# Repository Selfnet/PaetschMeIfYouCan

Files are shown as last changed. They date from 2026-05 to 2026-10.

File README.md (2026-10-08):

# P-tschMeIfYouCan
Ein Geschicklichkeitsspiel mit Spaß am Gerät

## Important: Name Entry Keyboard Behavior

This is a required interaction contract. Preserve it when changing the dashboard:

- **Enter in the first displayed input:** move to the second input if its name is empty or whitespace-only; otherwise submit both names and proceed to the leaderboard.
- **Enter in the second displayed input:** submit both names and proceed to the leaderboard, even when either name is blank. Empty or whitespace-only names skip that player's leaderboard entry.
- **Tab / Shift+Tab:** cycle between the name inputs, including wrapping; never submit names or advance to the leaderboard, even when both names are filled.

The inputs are displayed in result order (winner first), not fixed player-number order. These rules apply regardless of which player wins or whether the race is tied. Automatic name-entry timeout is separate from keyboard submission.

[Keyboard regression tests](Test_Server/tests/test_name_entry_keyboard.py) execute the dashboard's actual JavaScript handler. Run them when changing name entry or keyboard handling; they do not test live serial hardware.

## Leaderboard Policy

Each leaderboard shows one row per case-insensitive name, separately for each game mode and slot. Ranks compare each player's **best time**; equal times share a rank. The name uses the latest spelling, and **Set at** is the best attempt's timestamp (the latest matching attempt for equal best times). The **Attempts** column counts all saved scores for that name in the same mode and slot, including historical scores. Blank names are still skipped, and retrying a score save does not add an attempt.

After a race, that player's row is highlighted even when the new time is worse. A worse time appears as **This race** beneath the best time without changing the rank. A first score or strictly improved best earns a **NEW PB!** badge; matching an existing best does not. Idle browsing does not show current-race details or badges.

All attempt history remains in SQLite; grouping does not delete or rewrite scores and requires no database migration. A paginated browse freezes the best times, latest attempts, and counts at its opening snapshot. [Leaderboard regression tests](Test_Server/tests/test_leaderboard.py) cover case-insensitive grouping, best-time ranking, attempt counts, and snapshot pagination; [transport tests](Test_Server/tests/test_app.py) cover current-race highlighting and personal-best detection. Neither covers physical hardware or browser layout.

## Leaderboard Slots

Use **1-9**, including the numeric keypad, or the slot selector to choose a leaderboard while the game is ready. The shortcut also works while browsing the idle leaderboard, which refreshes to the selected slot. Slot switching is disabled during a race, name entry, post-race results, and the mode dialog. Digits typed into name inputs remain part of the name.

Each slot has independent scores and ranks for every game mode. Slot 1 retains all existing scores; slots 2-9 start empty. Switching never deletes scores. The selected slot is saved in SQLite and restored after backend or machine restarts, independently of browser storage. The slot is captured when a race starts, so delayed score writes cannot move a race into another slot.

The database remains at `LEADERBOARD_DB` or `~/.local/share/patchmeifyoucan/leaderboard.sqlite3`. Migration adds the slot column and a singleton selection setting without changing historical score IDs, timestamps, or mode IDs. Back up the database before deploying this migration. Source-only rollback to pre-slot code is unsafe: that code would combine all slots' scores. A database rollback also discards any scores recorded since its backup.

[Slot persistence and transport tests](Test_Server/tests/test_leaderboard_slots.py) cover migration, isolation, restart restoration, failed settings writes, race identity, and stale page rejection; they do not exercise physical hardware. [Slot keyboard tests](Test_Server/tests/test_leaderboard_slot_keyboard.py) execute the actual dashboard shortcut and selection helpers, including modifier, focus, and phase guards; they do not replace browser layout checks.

## Development

[Adding gamemodes](docs/gamemode-authoring.md) explains the board/session contract, registry, validation, and scoring identities. Start there when adding a mode; firmware protocols and deployment are outside its scope.

Run `uv run pytest -q` from `Test_Server/`. Node.js must be on `PATH` for the name-entry keyboard tests, which execute the dashboard's JavaScript handler.

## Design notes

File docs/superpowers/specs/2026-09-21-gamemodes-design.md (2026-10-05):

# Gamemodes Design

## Status and Goal

Historical design, implemented and deployed on `feat/gamemodes` through `194a6cb`. [The README](../../../README.md) documents the current name-entry keyboard contract and test prerequisites; this document records the original design, not current deployment instructions.

The gameplay and interaction decisions below reflect the conversation. Technical defaults introduced while writing this spec include 50-row pages, snapshot pagination, tick precision, and the detailed focus and error contracts. These are proposed implementation choices for review, not separately approved product requirements.

Introduce extensible, stateful gamemodes without changing the familiar switch overview and race flow. Ship Full Field, Half Field, and Quarter Field first. Keep mode logic independent of Flask, the browser, serial transport, and persistence so contributors can add modes without changing those integrations.

Work happens on `feat/gamemodes` in the canonical checkout's `.worktrees/gamemodes/` directory. Deployment is not part of this work.

## Existing Context

- `Test_Server/app.py` currently owns cached board feedback, expected cable identities, serial parsing, and application wiring. Serial readings become open/wrong/correct states before reaching the race.
- `Test_Server/race.py` owns the locked race lifecycle and hardcodes completion as all 48 ports being correct.
- `Test_Server/templates/index.html` renders each board as two rows of 24 ports. Port indices alternate top/bottom: column `i // 2`, row `i % 2`.
- `Test_Server/leaderboard.py` stores mode-independent scores and queries the top 10.
- `Test_Firmware/src/main.cpp` reads port identities and drives yellow/green LEDs locally. It does not receive host LED commands.

Related designs:

- [Post-race results](2026-08-28-post-race-leaderboard-design.md): background for race timing, result entry, persistence, and failure handling. This spec replaces its all-48 completion rule, top-10 restriction, and fixed leaderboard deadline; it is not an authoritative description of later name-entry changes.
- [Idle leaderboard](2026-08-30-idle-leaderboard-design.md): background for local browsing, dismissal, timestamps, and stale-response protection. This spec replaces its top-10 restriction and adds scrolling and navigation-driven inactivity handling; it does not redesign race controls.

Preserve current working behavior outside the changes explicitly described here, including simultaneous name-entry support, ties, per-player diagnostic stops, and result timing.

## Scope

Included:

- Board observations separated from mode-specific interpretation.
- Stateful, independently testable per-player mode sessions.
- Three built-in field modes and a documented authoring interface.
- A hidden keyboard-accessible main-screen mode selector.
- Generic mode objective, progress, stage, and port presentation.
- A hardware-independent boundary for future LED output.
- Per-mode leaderboards, existing-score migration, all-score browsing, and inactivity handling.

Excluded:

- Firmware modifications, a serial LED protocol, or sending LED commands.
- Plugin discovery, uploaded code, hot reloading, or a custom-mode editor.
- Additional shipped gameplay beyond the three field modes.
- Empty-board enforcement, anti-cheat measures, or fresh-insertion requirements for field modes.
- Leaderboard deletion or administration, durable recovery of unfinished races, and deployment.

## Built-in Rules

Each player has a separate 48-port board, arranged as two rows of 24 columns. Both players use the same selected mode.

| Mode ID | Label | Required region | Required ports |
| --- | --- | --- | --- |
| `full-field` | Full Field | All 24 columns | 48, indices 0-47 |
| `half-field` | Half Field | Leftmost 12 columns | 24, indices 0-23 |
| `quarter-field` | Quarter Field | Leftmost six columns | 12, indices 0-11 |

Half and Quarter Field are single-region objectives, not left-to-right sequences. Quarter Field therefore requires six top and six bottom ports. Ports outside the region are ignored, regardless of whether they are open, correct, or incorrectly patched.

All three modes reuse one implementation parameterized by required ports. In normal verification mode, each required port must contain its expected cable identity. Preserve the existing verification-bypass diagnostic behavior: occupied required ports count when verification is disabled. Verification is explicit evaluation context, not inferred from rendered feedback.

There is no unplugging prerequisite. Pre-patched ports count. At race start, evaluate the latest valid observation at elapsed time zero; an already-complete board may finish immediately. If no valid reading has arrived, the board is unknown and cannot complete until a valid observation is received. Do not add anti-cheat logic.

## Architecture

### GameBoard

One `GameBoard` per player owns the latest validated raw port identities and whether any valid observation has arrived. It exposes immutable observation snapshots and the fixed physical layout, including expected identities and coordinate/index helpers.

Keep raw identities available to custom modes rather than reducing all input to open/wrong/correct. Board updates must contain exactly 48 integer byte values; reject booleans, out-of-range values, malformed text, and partial frames. A rejected update leaves the previous observation intact and is not delivered to a session.

The serial adapter remains responsible for decoding and reversing wire order into the canonical port order. That reversal happens once. Modes do not know serial devices, wire ordering, or LED shift-register mappings.

### GameMode and ModeSession

A mode definition provides a stable ID, label, description, and a factory for fresh sessions. Use an explicit in-process registry with unique IDs; no dynamic plugin loading. Invalid definitions fail startup clearly rather than silently replacing another mode.

Each player receives a separate session at race start. A session owns its private gameplay state and supports:

- Initialization against the current observation and evaluation context at elapsed time zero.
- Observation updates with an immutable board snapshot and monotonic elapsed time.
- Periodic ticks with the latest observation and elapsed time, allowing timed stages to progress without new serial input.
- An immutable presentation snapshot after evaluation.

Reset or abandonment discards sessions. Sessions must not retain state across races or share mutable gameplay state between players. They have no Flask, Socket.IO, database, serial, or wall-clock dependencies and must not block on I/O.

The session snapshot contains:

- Short objective text and an optional stage label.
- Progress as a non-negative current value and positive total, with a short unit label; omit progress for objectives without a meaningful counter.
- Per-port target membership and semantic feedback: open, wrong, correct, or unknown. Inactive appearance is derived from target membership, not a substitute for the observation.
- A completion flag.
- Optional desired per-port LED states, described below.

Field modes report correct required ports out of required ports, for example `8 / 12 correct`. Stateful modes can change targets, instructions, and stages through the same contract. The browser contains no mode-ID-specific gameplay branches.

A pure ready-state preview supplies targets and presentation from current observations without advancing a race session. This preserves live board feedback before a race while ensuring race start always creates fresh gameplay state.

### Race Controller and Runtime

The race controller owns selection, race lifecycle, per-player session ownership, timing, result ordering, name entry, and deadlines. The selected mode is fixed for the entire race and its results. The runtime handles transport, persistence, and broadcasting.

Serialize selection, start, reset, observation delivery, tick evaluation, and completion under the authoritative controller lock. Capture one monotonic timestamp per transition so both start evaluations use the same origin. Never run persistence, serial I/O, or socket emission while holding that lock; publish immutable snapshots and transition results afterward.

Publish each validated board observation and deliver it to the current session in the same locked transition. Start reads both current boards, creates both sessions, and evaluates both at the shared start timestamp in one locked transition. Serial decoding can happen outside the lock, but cached snapshots must not be captured there and subsequently delivered to a replacement session. Lock acquisition determines whether an observation precedes or follows start/reset.

First completion remains latched. Later observations, ticks, or unplugging cannot change the recorded finish time. Preserve millisecond floor timing and existing manual-stop behavior. Ordinary mode progression must be broadcast even when race phase and completion status do not change.

An individual diagnostic stop freezes that player's displayed clock, but while the shared phase remains racing the unfinished session continues receiving observations and ticks using elapsed time from the original race start. A later completion replaces the manual stop with its actual completion timestamp. Global stop, or stopping both players, ends evaluation for all sessions; physical observations may still update. Reset discards those sessions. Completed sessions no longer advance.

Out-of-lock operations carry immutable origin tokens. Score persistence carries the completed race ID and mode ID; page reads carry the browsing request ID, mode ID, snapshot boundary, and race ID for post-race views. Apply resulting controller updates only if the expected race, mode, and phase still match. A late write may finish saving already-confirmed submissions, but cannot modify a replacement race or revive an expired view. Browser responses are likewise checked against the active browsing token. Persistence and page responses never refresh inactivity deadlines.

Use the existing periodic background mechanism for ticks; this version promises no sub-second scheduling for time-driven modes. Pass actual elapsed monotonic time, not a count of ticks. Serial-driven completion retains its arrival-time resolution.

## Lifecycle and Errors

- Server startup selects Full Field.
- Selection is accepted only in `ready`, with a known registered mode ID. Both players change together.
- Selection survives explicit resets, leaderboard dismissal, and automatic return to ready. It does not persist across server restarts.
- Start creates new independent sessions and evaluates current valid observations immediately.
- Reset discards mode progress but retains physical observations and selected mode.
- A reconnect receives mode metadata, phase, objective, progress, port feedback, and current race identity without reconstructing gameplay in JavaScript.
- Invalid hardware input is rejected before mode evaluation.
- A session exception or invalid output stops the race with a visible, recoverable error, logs diagnostic details, and creates no leaderboard submissions. Reset returns to ready. A failing ready preview shows an error and prevents starting that mode, while still allowing another mode to be selected.

## Main-Screen UI

### Mode Selector

The switch overview remains the default. The mode selector is hidden initially and can be opened only while ready. Display a compact current-mode label, such as `Quarter Field · 12 ports`, and a subtle `M: mode` hint while ready. Other modes can omit the port count if inappropriate.

- `M` opens the selector; `M` again cancels it.
- Arrow keys move between options in registry order without wrapping at the ends.
- Tab and Shift+Tab move focus through selectable options and the close control in normal DOM order.
- Enter or clicking an option confirms it, updates the shared selected mode, and closes the selector.
- Escape cancels without changing the selection.
- Space does not start a race while the selector is open.
- Opening focuses the selected mode. Closing restores focus to the overview's mode control.

Each option shows its label and short description. Browsing focus does not change the shared selection or preview; only confirmation does. The selector's visibility and focus are browser-local. Accepted selection is broadcast to every browser. An authoritative phase change closes any open selector. Stale selection requests after a race starts are rejected.

Use a labeled modal dialog with ordinary option buttons and a close button. Background controls are inert while it is open. Tab/Shift+Tab visits every option and the close button, wrapping at the dialog boundary; arrows move only among mode options. If another browser changes the mode, update the selected marker without moving the local browsing focus. Enter confirms the locally focused option. On an external phase change, move focus to an appropriate element of the new view rather than a now-hidden mode control.

Mode shortcuts never intercept text entry; `M` remains a normal character in a name field. The selector and local leaderboard cannot be open simultaneously; their shortcuts do not open one behind the other.

### Board Presentation

Keep all 48 physical positions visible in the existing two-row arrangement. Required ports retain clear open/wrong/correct feedback. Unused ports are dimmed with readable numbers, and their state does not affect objective progress.

Show a concise objective and progress for each player, plus a stage label when present. Independent player sessions may show different stages and targets. Preserve timers and existing result/name-entry screens. Mode identity remains visible on results and leaderboards so the meaning of a time is clear.

Unknown observations are not presented as verified empty ports. Accessibility labels identify port number, whether it is required, and its feedback. Focus must remain visibly distinct from completion highlighting.

## Future LED Boundary

Sessions may describe optional LED intent as a complete 48-port frame of yellow/green boolean states. Absence means the mode supplies no host LED intent; it is distinct from an explicitly all-off frame. Frames describe desired state, not commands or electrical indices.

LED intent is separate from browser feedback because their capabilities differ. A future hardware adapter can map canonical port indices to firmware commands and handle capability negotiation, writes, and reconnects without changing game rules.

This version validates and tests the output contract but does not send it. Existing firmware behavior remains unchanged. It does not introduce blinking, brightness, animations, transport retries, or a new wire protocol.

## Per-Mode Leaderboards

### Persistence and Ranking

Store a stable mode ID with each score, propagated from the completed race through score submission. Never infer score mode from the current selection at insertion time.

Migrate all existing rows to `full-field`, preserving IDs, names, times, timestamps, and race/player uniqueness. Migration must be transactional and safe on repeated initialization. Add an index supporting per-mode score ordering.

Rank only within the selected mode. Preserve competition ranking for equal millisecond durations and deterministic ordering by duration, creation time, then database ID. Mode IDs are durable scoring identities: incompatible rule changes should receive a new ID rather than silently sharing old rankings.

The post-race leaderboard uses the completed race's mode. The local leaderboard uses the current selected mode. Keep rank, name, time, and locally formatted creation timestamp columns, and current-race highlighting wherever those rows occur.

### All-Score Browsing

Expose every score for the mode, not just the top 10. Fetch bounded pages on demand, initially 50 rows per page. A browsing snapshot captures the maximum included row ID on opening, and every page filters to that boundary. New inserts become visible when reopening, preventing duplicates or skipped rows as new scores arrive during browsing. Ranking is computed across the entire mode snapshot before pagination, not separately per page.

Use boundary `0` for an empty snapshot. Every page applies both the mode filter and `id <= boundary`, even for an empty snapshot. Page position is a validated non-negative offset into that snapshot's deterministic ordering. Deletion and editing of scores are outside this feature, so inserts alone cannot shift offsets within the boundary.

Requests and targeted responses identify the mode, browsing request, snapshot boundary, and page position. Validate bounds server-side and keep the page size capped. Each browser tracks its own rows, focus, and scroll position. Ignore responses belonging to a closed view, previous mode, old race, or replaced browsing request.

Do not put the growing row collection in periodic shared `game_state` broadcasts. Shared state supplies race identity, mode, timeout, and persistence status; targeted page responses supply rows. Periodic countdown updates must not recreate the table or reset browsing position.

If the selected mode changes in another browser, close the local leaderboard so it cannot continue displaying an incorrectly labeled mode. An active race transition also closes the local view, as today.

### Keyboard and Scrolling

Use a bounded scroll area inside the leaderboard view rather than scrolling the entire kiosk page. Open at the highest-ranked scores and retain heading focus on entry.

- Up/Down moves through score rows and scrolls the focused row into view. From the heading, Down enters the first row.
- Tab/Shift+Tab follows normal focus order through loaded rows and controls.
- Prefetch the next page near the loaded end. An accessible load-more control after loaded rows remains available if fetching has not completed; Enter activates it and moves focus to the first newly loaded row once available. Down at the last loaded row similarly requests and advances when more scores exist.
- Repeated navigation during a pending request must not issue duplicate page loads or lose focus. Loading failures retain existing rows and allow retry or dismissal.
- At the final score, Down stays on that row; Tab can continue to controls.
- Preserve `L` and Escape dismissal for both leaderboard views and Space dismissal for post-race. Space remains inert in the local idle leaderboard.

Preserve native table semantics and make each loaded score row focusable with `tabindex="0"`, deliberately allowing Tab through scores as requested. Give the scroll area an accessible label and keep a visible close control before the table so long lists do not require tabbing through every row to dismiss. Append rows without replacing existing nodes. Track focused rows by database ID. During navigation-triggered loading, retain focus on the initiating row or load-more control; move to the first appended row only if the same view and navigation intent remain current. If focus has moved or the view has closed, do not steal it when the response arrives. On failure, retain focus and expose a retry control with an announced error.

No automatic jump to current-race rows; initial browsing starts at the top. Highlight those rows when reached.

### Inactivity

The post-race leaderboard retains a server-owned 60-second deadline, now refreshed by valid user navigation or scrolling. Send an activity event tied to the current race ID. Validate phase and race ID and process expiry before accepting activity so late events cannot revive an expired view. Either connected viewer can extend the shared post-race deadline.

The idle leaderboard remains browser-local with its existing 60-second deadline, refreshed locally by the same interactions. It never changes authoritative race state. Throttle continuous scroll notifications; page responses, countdown rendering, reconnects, and programmatic scrolling alone do not count as activity. Navigation that causes programmatic scrolling counts once as the initiating user action.

Keep a subtle remaining-time indicator. Dismissal and automatic expiry restore the overview and appropriate focus.

### Failure Handling

Database migration, insertion, or read failures remain non-fatal to the kiosk, using the existing unavailable-store fallback and visible persistence error behavior. Scores must never fall back into another mode's leaderboard. Page failures preserve loaded rows, allow retry, and leave dismissal usable.

## Contributor Documentation

Add a concise mode-authoring guide during implementation, linked from the project README. Document the registry entry, observation layout, evaluation context, session lifecycle, output validation, tick precision, LED intent, and stable mode IDs.

Use built-in field modes as the static example and a small test fixture to demonstrate independent stateful stages and timed advancement. No extra production gamemode is required. A new mode should require only its definition/session, registry entry, and tests, not Flask routes, browser conditionals, or database schema edits.

## Verification and Acceptance

### Domain Tests

- Canonical top/bottom coordinates and exact full/half/quarter target sets.
- Valid raw observations, unknown initial state, malformed-frame rejection, and raw identity preservation.
- Required open/wrong ports prevent completion; inactive ports never do.
- Existing verification bypass remains explicit and functional.
- Pre-patched ports count, including immediate completion at start and zero-duration ties.
- Independent sessions, fresh state on reset/start, staged target changes, and time-driven transitions without new readings.
- First-completion latching, millisecond timing, manual-stop semantics, and stop/reset behavior.
- Selection allowed only while ready and retained across every reset path.
- Invalid session output or exceptions stop play recoverably without scores.
- Optional LED output is validated and never written to hardware.

### Persistence and Integration Tests

- Migration of a pre-mode database preserves scores and assigns Full Field; reopening is idempotent.
- Rankings, ties, ordering, and all pages remain isolated by mode.
- More than one page can be browsed without skipped/duplicated entries, including concurrent inserts and ties at page boundaries.
- Completed-race mode travels through submissions independently of later selection.
- Reconnect restores current objectives and progress, including different stages per player.
- Invalid or stale selection, page, and activity events cannot alter a race or reopen a view.
- Countdown broadcasts do not replace browser-local rows or focus.
- Inactivity extends on valid user activity, expires normally, and rejects late/stale activity.
- Database failures do not prevent starting the next race.
- Delayed persistence and page responses cannot update a reset, replaced, or expired race/view.
- Observation/start/reset ordering and timed-session behavior after individual and global stops follow the controller contract.
- Empty browsing snapshots remain empty despite concurrent inserts until reopened.

### Browser Acceptance

- Existing switch overview remains the default and fits the deployed 1920x1080 display.
- M, arrows, Tab/Shift+Tab, Enter, Escape, and mouse selection follow the specified behavior.
- Cancelling leaves selection unchanged; selection updates both players and closes the selector.
- Name entry accepts M normally; Space cannot start behind a selector or local leaderboard.
- Target dimming, progress, objective, and stage labels are legible without moving physical port positions.
- All mode scores are reachable by keyboard, focus stays visible, and loading/retry controls work.
- Post-race highlights and tied ranks remain correct beyond the first page.
- Neither countdown updates nor page appends reset focus or scroll position.
- Shared post-race and local idle inactivity handling preserve their separate ownership.
- Selector focus cannot escape into background controls; external selections update the marker without stealing focus.
- A delayed page response cannot steal focus after the user navigates away from its initiating row or control.

## Next Step

Implementation and deployment are complete. Read [the authoring guide](../../gamemode-authoring.md) for the implemented mode API; it does not cover firmware or deployment. The original design excluded deployment, which the user later authorized separately.

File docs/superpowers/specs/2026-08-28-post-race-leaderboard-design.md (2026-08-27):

# Post-Race Results and Leaderboard Design

## Goal

After both players complete a race, show a combined result and name-entry screen, collect optional player names using the game PC's keyboard, persist named results in SQLite, and show a top-10 leaderboard before returning to the ready screen.

The result screen must display the exact message `you were able to success`.

## Scope

This design adds:

- Authoritative millisecond race timing.
- Winner, second-place, and tie results.
- Sequential keyboard name entry for both players.
- Optional leaderboard participation by leaving a name empty.
- A local persistent top-10 leaderboard.
- Automatic and keyboard-driven post-race transitions.

Leaderboard administration, remote synchronization, multiple simultaneous races, and profanity filtering are out of scope.

## Architecture

The Flask server owns one kiosk state machine:

```text
ready -> racing -> name_entry -> leaderboard -> ready
            |
            +-> stopped -> ready
```

Only a race in `racing` may accept player completion. Both players completing transitions the race to `name_entry`. Space while racing stops the race without creating a result and enters `stopped`; Space from `stopped` resets to `ready`.

The control page's per-player stop actions remain diagnostic controls. They freeze that player's displayed clock but do not mark the player as verified complete. The race remains in `racing` while at least one player clock is active and enters `stopped` if both players are manually stopped. A later valid serial completion may replace an individual manual stop while the race remains in `racing`, using the actual monotonic completion time. Reset from any phase abandons the active or partially entered race and returns to `ready`.

The backend is divided into three responsibilities:

- `app.py` owns Flask routes, Socket.IO wiring, and serial integration.
- `race.py` owns the locked race state machine, timing, result ordering, name-entry state, and deadlines.
- `leaderboard.py` owns SQLite initialization, insertion, and queries.

The server emits a `game_state` Socket.IO payload after every state change and immediately when a browser connects. The payload contains enough information to render the current phase after a refresh without reconstructing state in the browser.

## Race Timing and Completion

Race start and each player's first valid completion are recorded with `time.monotonic_ns()`. Stored and displayed durations use integer floor division: `(completed_ns - started_ns) // 1_000_000`.

A serial update completes a player only when it contains exactly 48 cells and every cell has verified state `2`. Open state `0`, wrong-cable state `1`, incomplete messages, and duplicate complete updates do not complete a player. Completion is idempotent: the first valid completion timestamp wins.

The result order is ascending by duration. If both durations are equal to the millisecond, the result is a tie. Tied players receive equal visual treatment; Player 1 is prompted first only to make sequential keyboard entry deterministic.

The existing periodic clock updates continue to drive the live display, but the final result and leaderboard always use the server's recorded duration.

## Result and Name-Entry Screen

The race dashboard is replaced by one combined result and name-entry screen when both players complete. It shows:

- The exact message `you were able to success`.
- The winner and second-place player with `mm:ss.mmm` times.
- Equal tie labels instead of an invented winner when times match.
- Two visible name fields associated with the displayed results.
- Actual keyboard focus and a clear visual highlight on the currently active field.
- A subtle name-entry countdown.

Name entry follows result order. The active player can enter up to 12 printable Unicode characters. Leading and trailing whitespace is removed. A name containing only whitespace is empty.

Pressing Enter confirms the active field and advances to the next player. Enter on an empty field skips that player. Repeated Enter therefore skips both players and advances immediately. Space is ordinary name input during this phase and must not trigger race controls.

A 120-second idle deadline starts when the server enters `name_entry`. Draft changes are sent to the server and reset that deadline. Confirming the first player starts a fresh 120-second deadline for the second and moves actual keyboard focus to that field. When the deadline expires:

- Already confirmed non-empty names remain eligible for insertion.
- Confirmed empty names remain skipped.
- The active draft and all unresolved players are skipped.
- The kiosk advances to the leaderboard.

The countdown uses restrained footer copy: `Leaderboard in 1:42 - empty names are skipped`.

## Leaderboard Screen

Each non-empty player submission creates an individual leaderboard entry. Winners and second-place players are treated identically for ranking; only completion time determines leaderboard position.

The screen displays the top 10 entries with:

- Rank.
- Name.
- Completion time in `mm:ss.mmm`.

Equal millisecond durations use competition ranking, such as `1, 1, 3`. Ordering among equal times is stable by creation time and database ID. Entries from the race that just finished are highlighted when they appear in the top 10.

The leaderboard is shown even when both players skip name entry. Its 60-second deadline starts when the server enters `leaderboard`. A subtle footer displays `Next race in 1:00 - press Space to continue` and counts down. The screen returns to `ready` when that deadline expires or immediately when Space is pressed.

## Server State and Events

Every race has a unique `race_id`. Client events include the current `race_id`; stale or duplicate events are ignored.

The server-to-client `game_state` payload includes:

- Current phase and `race_id`.
- Live or final player durations.
- Completion and result order.
- Active name-entry player, confirmed/skipped state, and current drafts.
- Remaining seconds for the active deadline.
- Top-10 rows and IDs belonging to the current race.
- A non-fatal persistence error message when needed.

The browser sends:

- `name_draft` with the active player's full draft after an edit.
- `submit_name` with the active player's full draft when Enter is pressed.
- `dismiss_leaderboard` when Space is pressed on the leaderboard.

The server validates player order, phase, race ID, printability, and length before changing state. Accepted draft activity extends the idle deadline. Invalid data leaves state unchanged.

A Socket.IO background watchdog evaluates monotonic deadlines and emits countdown updates. Deadlines continue while the browser is disconnected. Reconnecting receives the current phase and remaining time.

## Persistence

The database defaults to:

```text
~/.local/share/patchmeifyoucan/leaderboard.sqlite3
```

The default path is resolved from `Path.home()` for the service account (`patchme` on the deployed PC). `LEADERBOARD_DB` may override it. The parent directory is created at startup. Keeping the database outside the checkout prevents `just sync --delete` from removing event data.

Python's built-in `sqlite3` module is sufficient. Each operation uses its own connection with a busy timeout. Schema initialization is idempotent.

`created_at` is an ISO 8601 UTC timestamp.

```sql
CREATE TABLE leaderboard_entries (
    id INTEGER PRIMARY KEY,
    race_id TEXT NOT NULL,
    player_number INTEGER NOT NULL CHECK (player_number IN (1, 2)),
    name TEXT NOT NULL CHECK (length(name) BETWEEN 1 AND 12),
    duration_ms INTEGER NOT NULL CHECK (duration_ms >= 0),
    created_at TEXT NOT NULL,
    UNIQUE (race_id, player_number)
);

CREATE INDEX leaderboard_time_idx
    ON leaderboard_entries (duration_ms, created_at, id);
```

When all players are confirmed, skipped, or timed out, the server inserts all non-empty confirmed names in one transaction. The unique key makes retries idempotent. The server then queries the top 10 and enters `leaderboard`.

## Failure Handling

Database failures must not trap the kiosk. An insertion or query error is logged, the state still advances to `leaderboard`, and the screen shows a restrained `Scores could not be saved` notice. Readable existing rows may still be displayed.

Malformed or stale Socket.IO events are rejected without changing state. Duplicate serial completion messages do not alter final times. Reset cancels active post-race deadlines and clears in-memory drafts.

If the service restarts during a race or name entry, the in-progress race is lost and starts in `ready`; completed leaderboard rows remain in SQLite. Durable recovery of an unfinished race is out of scope.

## Testing

### Race State Tests

Use a fake monotonic clock and direct completion calls without serial hardware. Cover:

- All valid state transitions.
- Global and per-player manual stops never creating a result.
- Millisecond timing.
- Exactly 48 verified cells being required for completion.
- Wrong, open, and incomplete states not completing a player.
- First-completion idempotency.
- Winner ordering and exact ties.
- Sequential name submission.
- Empty Enter and repeated Enter skips.
- Confirmed first-player data surviving second-player timeout.
- Draft activity extending the idle deadline.
- Name-entry timeout behavior.
- Leaderboard Space dismissal and 60-second timeout.
- Reset abandoning unfinished results.

### Leaderboard Tests

Use a temporary SQLite database. Cover:

- Schema initialization and reopening persistence.
- Atomic insertion of zero, one, or two player entries.
- Duplicate race/player protection.
- Name and duration validation.
- Top-10 ordering and truncation.
- Competition ranks (`1, 1, 3`) for equal times.

### Integration and UI Tests

Flask-SocketIO tests cover initial connection state, reconnect during each phase, stale `race_id` rejection, synchronized state across clients, and non-fatal database errors.

Browser acceptance at the deployed display size verifies:

- The exact success message and correct result ordering.
- No overflow or overlapping text.
- Obvious sequential keyboard focus.
- The 12-character limit and printable input.
- Empty Enter and repeated Enter behavior.
- Both subtle countdowns.
- New-row highlighting.
- Phase-specific Space behavior.
- Return to a clean ready screen.

## Acceptance Criteria

1. Both verified boards completing automatically show the combined result and name-entry screen.
2. Final times are server-recorded to milliseconds and survive browser refresh during post-race phases.
3. The exact text `you were able to success` is visible.
4. Empty Enter skips one player; repeated Enter skips both.
5. A 120-second idle timeout saves confirmed names and skips unresolved players.
6. Both name-entry and leaderboard deadlines are shown subtly.
7. Named players are stored individually and atomically in SQLite.
8. The top 10 persists across service restarts and deployments.
9. The leaderboard dismisses after 60 seconds or immediately on Space.
10. Any database failure leaves the kiosk able to continue to the next race.

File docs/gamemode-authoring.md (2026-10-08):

# Adding Gamemodes

A mode owns its objective, per-port feedback, progression, and completion. The
shared runtime owns board input, race timing, publication, and score persistence.
Add a definition and session, not a route, frontend mode-ID branch, or database
column. Firmware protocols and deployment are outside this guide.

## Board Input

[`board.py`](../Test_Server/board.py) defines the canonical board model and
coordinate helpers; use it rather than interpreting serial frames inside a mode.
`BoardObservation.identities` is either `None` (no valid observation yet) or an
immutable tuple of 48 byte identities. A malformed frame does not replace the
last valid observation. Unknown is not an all-open board; do not infer completion
from missing input. Identity `255` (`OPEN_ID`) means an open port.

Indices `0..47` are column-major across 24 columns and two rows:
`coordinates(index) == (index // 2, index % 2)` and
`port_index(column, row) == column * 2 + row`. Row 0 is the outside socket, row 1
the underside. Index 0/1 is the leftmost column; index 46/47 is the rightmost.
`EXPECTED_IDS` uses this same order. The adapter reverses wire order once, in
`decode_serial_frame`; neither sessions nor presentation code should reverse it.

## Definition And Lifecycle

[`gamemodes.py`](../Test_Server/gamemodes.py) is authoritative for the frozen
value types, protocol, and validator. The definition has these constructor fields:

```python
GameMode(
    id: str,
    label: str,
    description: str,
    required_port_count: int | None,
    session_factory: Callable[[], ModeSession],
    preview: Callable[[BoardObservation, EvaluationContext], ModeSnapshot],
)
```

IDs, labels, and descriptions must be nonempty. `required_port_count` is positive
or `None` for a mode without a fixed count; it is metadata, not a completion rule.
Both preview and session methods receive `EvaluationContext(verify: bool)`
explicitly. Define the mode's verification policy from that context, not globals.
For the built-in fields, verification requires matching `EXPECTED_IDS`; with it
off, any non-open identity is correct. Open remains open in either case.

Preview must be pure: return a ready-state presentation without creating,
advancing, or resetting a race session. Repeated preview calls must not change
future race behavior. `GameMode.new_session()` calls the factory with no arguments;
return a fresh object for every player on every start. Never return a singleton or
share mutable stage state between sessions or races. The runtime rejects the same
object returned for both players, but that check does not prove factory freshness.

Implement all three `ModeSession` methods with these signatures:

```python
def initialize(self, observation: BoardObservation,
               context: EvaluationContext, elapsed_ns: int) -> ModeSnapshot: ...
def observe(self, observation: BoardObservation,
            context: EvaluationContext, elapsed_ns: int) -> ModeSnapshot: ...
def tick(self, observation: BoardObservation,
         context: EvaluationContext, elapsed_ns: int) -> ModeSnapshot: ...
```

`initialize` receives the current board and elapsed time `0` at race start; it may
complete an already-satisfied objective immediately. During racing, `observe`
runs for valid board input (including repeated input) and verification changes.
`tick` evaluates time-dependent progress even without new input. Calls stop for
completed players. Reset discards sessions and returns to pure previews;
reconnect publishes cached presentations without reinitializing sessions.

Published `game_state.browse_epoch` identifies the runtime's leaderboard browse
generation. Browsers close local browsing when it changes, including same-mode
confirmation or a ready-state reset. Ordinary observations, progress ticks, and
persistence updates retain the generation; modes do not manage it. The lifecycle
and snapshot in [`race.py`](../Test_Server/race.py) define this transport contract,
not score storage or mode completion.

`elapsed_ns` is monotonic time since the **original shared race start**, not
displayed milliseconds or time since the last callback. A manually stopped
player's diagnostic display clock freezes, but its session still evaluates on
that original elapsed time while the race remains active. Store stage timestamps
in the session and subtract them from `elapsed_ns`; do not count callbacks.
[`race.py`](../Test_Server/race.py) owns these lifecycle and completion rules.
[`app.py`](../Test_Server/app.py) owns runtime scheduling and transport, not mode
logic: its background loop sleeps one second between ticks. Nanosecond precision
does not guarantee subsecond callbacks; completion is timestamped when evaluated.

## Output Contract

Return frozen `ModeSnapshot(objective, stage, progress, ports, complete,
led_intent=None)` values. Nested `Progress`, `PortPresentation`, and `LedState`
are frozen too. Validation requires the exact dataclass types, not subclasses or
dictionary lookalikes, and exact tuples rather than lists:

- `objective`: nonempty string; `stage`: string or `None`.
- `progress`: `Progress(current, total, unit)` or `None`; current is a nonnegative
  integer, total a positive integer, unit a nonempty string. Current may exceed
  total. Booleans are not integer counters.
- `ports`: exactly 48 `PortPresentation(required: bool, feedback: str)` entries
  in canonical order. Feedback is `open`, `wrong`, `correct`, or `unknown`.
  Required flags express the current objective; completion is the mode's own
  boolean, not a runtime count of required/correct ports.
- `led_intent`: `None` or exactly 48 `LedState(yellow: bool, green: bool)` entries.
  Absence differs from an explicit all-off tuple. This is optional intent only:
  the runtime validates and publishes it but **never writes it to serial**.

Every preview and lifecycle result passes `validate_snapshot` before publication.
An exception or invalid race output stops the race with a recoverable mode error;
invalid previews prevent starting until recovery. Keep mode code free of I/O.

## Registration And Scores

Insert production definitions in the explicit `BUILTIN_MODES = ModeRegistry(...)`
construction at the end of `gamemodes.py`. There is no plugin discovery; registry
order determines selector order and duplicate IDs are rejected. For isolated
tests, inject `ModeRegistry([...])` through `create_app(registry=...)`, which returns
`(app, socketio)`. Include `full-field`: it is the runtime's initial selected ID.
The staged fixture belongs in tests, not the production registry.

Treat a mode ID as a durable scoring identity. Scores capture the race's selected
ID and leaderboard queries filter by it. Changing labels does not migrate scores;
renaming/removing an ID leaves old rows stored, without a selector entry. Assign
a new ID when changed rules make old times incomparable; reuse an ID only when
that comparison remains valid. [`leaderboard.py`](../Test_Server/leaderboard.py)
owns storage and migration: legacy rows without a mode column are assigned
`full-field`, preserving their IDs and existing data. New modes need no schema
change; do not retag historical scores to a new ruleset.

Leaderboard slots are a separate event namespace, not mode IDs. The runtime
captures the slot alongside the mode at race start, and queries filter by both.
Modes must not select slots or handle persistence. The [leaderboard slot contract](../README.md#leaderboard-slots)
describes switching, restart persistence, migration, and rollback constraints;
it does not define mode rules or firmware behavior.

## Examples And Checks

- [`_evaluate_field` and `_FieldSession`](../Test_Server/gamemodes.py) show static
  objectives sharing a pure evaluator for previews and all lifecycle methods.
  Start here for fixed required-port sets; they do not illustrate stage state.
- [`StagedSession` and `STAGED_MODE`](../Test_Server/tests/mode_fixtures.py) show
  independent patch/wait stages, elapsed-time timestamps, and a pure initial
  preview. This is a test fixture, not a production verification-policy template:
  its stage transition deliberately checks the exact raw port-0 identity.
- [`test_gamemodes.py`](../Test_Server/tests/test_gamemodes.py) covers validation,
  freshness, pure previews, and staged ticks; [`test_race.py`](../Test_Server/tests/test_race.py)
  covers shared timing and failure recovery. [`test_app.py`](../Test_Server/tests/test_app.py)
  covers transport and cached reconnects, not physical browser or hardware tests.

Exercise unknown/open/wrong/correct input, verification changes, repeated input,
fresh starts, independent players, time-only progression, and invalid outputs.
Verify a custom injected registry restores each player's stage on reconnect
without special routes or rendering branches, and LED intent causes no serial
write. Run from `Test_Server`:

```sh
uv run pytest -q
uvx ruff check board.py gamemodes.py race.py leaderboard.py app.py tests
```

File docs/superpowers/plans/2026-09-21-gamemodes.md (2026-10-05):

# Gamemodes Implementation Plan

Status: implemented and deployed on `feat/gamemodes` through `194a6cb`. This is the historical implementation plan; checkbox records are not a current work queue. [The authoring guide](../../gamemode-authoring.md) describes the implemented API, and [the README](../../../README.md) records the important name-entry keyboard contract and test prerequisites. Local `.superpowers/sdd/` acceptance reports are not versioned; automated coverage lives in `Test_Server/tests/`.

> **For agentic workers:** REQUIRED SUB-SKILL: Use superpowers:subagent-driven-development (recommended) or superpowers:executing-plans to implement this plan task-by-task. Steps use checkbox (`- [ ]`) syntax for tracking.

**Goal:** Add extensible field gamemodes, a keyboard-accessible selector, and per-mode score browsing while retaining the familiar kiosk UI and race flow.

**Architecture:** Move validated raw observations and physical layout into a pure board module, and gameplay into independent per-player mode sessions. Keep authoritative state transitions under the existing race controller lock, with persistence and Socket.IO work outside it. Render generic server-owned presentations in the existing template; keep dialog focus and paginated leaderboard browsing local to each browser.

**Tech Stack:** Python >=3.11, Flask, Flask-SocketIO threading mode, SQLite, pytest, vanilla JavaScript/CSS, existing local Socket.IO client. Browser acceptance uses the existing deterministic harness and agent-browser; no frontend framework or production dependency is needed.

## Global Constraints

- Work happens on `feat/gamemodes` in the canonical checkout's `.worktrees/gamemodes/` directory. Deployment is not part of this work.
- Preserve current working behavior outside the changes explicitly described here, including simultaneous name-entry support, ties, per-player diagnostic stops, and result timing.
- Both players use the same selected mode.
- Full Field: `full-field`, 48 ports, indices 0-47. Half Field: `half-field`, 24 ports, indices 0-23. Quarter Field: `quarter-field`, 12 ports, indices 0-11.
- Half and Quarter Field are single-region objectives, not left-to-right sequences.
- There is no unplugging prerequisite. Pre-patched ports count.
- Server startup selects Full Field. Selection survives every reset path but not server restarts.
- Board updates must contain exactly 48 integer byte values; reject booleans, out-of-range values, malformed text, and partial frames.
- Preserve millisecond floor timing and existing manual-stop behavior.
- This version promises no sub-second scheduling for time-driven modes.
- Fetch bounded pages on demand, initially 50 rows per page. Use boundary `0` for an empty snapshot.
- The post-race leaderboard retains a server-owned 60-second deadline. The idle leaderboard remains browser-local with its existing 60-second deadline.
- Keep rank, name, time, and locally formatted creation timestamp columns, and current-race highlighting wherever those rows occur.
- Keep all 48 physical positions visible in the existing two-row arrangement.
- No firmware modifications, host LED writes, plugin discovery, new production modes beyond the three field modes, leaderboard administration, or unfinished-race recovery.
- User clarification: preserve all existing UI look and feel not explicitly changed. The selector must look like the current UI, not a redesign. Add the suggested compact bottom bar for current-mode information and contextual shortcuts.
- This document is a plan, not authorization to deploy, push, or commit. During execution, make logical commits at task boundaries only when authorized; otherwise retain those boundaries for review.

---

## Sources and Scope

- [Gamemodes design](../specs/2026-09-21-gamemodes-design.md): authoritative gameplay, concurrency, UI, persistence, and acceptance requirements. Read before implementation; the user has now requested planning, not implementation.
- [Post-race design](../specs/2026-08-28-post-race-leaderboard-design.md): historical lifecycle and persistence context. Its all-48 rule, top-10 limit, fixed leaderboard deadline, and older name-entry details do not override current code or this spec.
- [Idle leaderboard design](../specs/2026-08-30-idle-leaderboard-design.md): local-view ownership and existing dismissal behavior, not the new pagination contract.
- `Test_Server/templates/index.html`: authoritative visual baseline. In particular, preserve `.race-stage`, `.stage-header`, `.player-panel`, `.clock-display`, board geometry, and result cards.
- `Test_Server/tests/browser_harness.py`: local fake clock and temporary database, with no serial threads. Use for acceptance; never exercise these scenarios on the deployed PC.

All paths below are relative to `/Users/amtmann/workspace/paetsch-me-if-you-can/PaetschMeIfYouCan/.worktrees/gamemodes`. Run Python commands from its `Test_Server` directory. The parent workspace's `just check` targets the canonical checkout, not this worktree; it is not evidence for this implementation.

## File Boundaries

| File | Responsibility |
| --- | --- |
| Create `Test_Server/board.py` | Immutable raw observations, expected identities, coordinate helpers, validated board cache |
| Create `Test_Server/gamemodes.py` | Frozen presentation/context values, session protocol, explicit registry, output validation, one parameterized field-mode implementation |
| Modify `Test_Server/race.py` | Own boards, selection, verification context, sessions, lifecycle, origin tokens, deadline validation |
| Modify `Test_Server/leaderboard.py` | Transactional migration, explicit score mode, snapshot boundary, ranked bounded pages |
| Modify `Test_Server/app.py` | Decode serial, transport raw observations, selection/page/activity events, outside-lock persistence |
| Modify `Test_Server/templates/index.html` | Existing styling plus mode bar/dialog, generic board rendering, local paginated browsing |
| Create `Test_Server/tests/test_board.py`, `test_gamemodes.py` | Pure-domain behavior and malformed contracts |
| Create `Test_Server/tests/mode_fixtures.py` | Non-production staged/timed and failing sessions shared by tests/harness |
| Modify `Test_Server/tests/test_race.py`, `test_app.py`, `test_leaderboard.py` | Lifecycle, races between operations, migration, targeted transport |
| Modify `Test_Server/tests/browser_harness.py` | Raw observations, multi-page fixtures, deterministic failure/delay controls |
| Create `docs/gamemode-authoring.md`; modify `README.md` | Contributor API and annotated entry link |

Do not change `Test_Server/templates/control.html`, firmware, deployment helpers, dependency lockfiles, or global CSS merely for consistency. Keep the current single-template frontend organization; do not add a build tool as part of this feature.

## Shared Contracts

These names are the interfaces between tasks. Frozen dataclasses contain only frozen nested values; serialization to fresh JSON dictionaries happens at the transport boundary.

```python
# board.py
NUM_PORTS = 48
OPEN_ID = 255
# EXPECTED_IDS: tuple[int, ...], moved unchanged from app.py
# coordinates(index: int) -> tuple[int, int] returns (column, row), zero-based
# port_index(column: int, row: int) -> int
# BoardObservation(identities: tuple[int, ...] | None)
# GameBoard.snapshot() -> BoardObservation
# GameBoard.update(values: object) -> BoardObservation  # raises ValueError

# gamemodes.py
# EvaluationContext(verify: bool)
# PortPresentation(required: bool, feedback: str)
# Progress(current: int, total: int, unit: str)
# LedState(yellow: bool, green: bool)
# ModeSnapshot(objective: str, stage: str | None, progress: Progress | None,
#              ports: tuple[PortPresentation, ...], complete: bool,
#              led_intent: tuple[LedState, ...] | None = None)
# ModeSession.initialize(observation, context, elapsed_ns) -> ModeSnapshot
# ModeSession.observe(observation, context, elapsed_ns) -> ModeSnapshot
# ModeSession.tick(observation, context, elapsed_ns) -> ModeSnapshot
# GameMode(id, label, description, required_port_count, session_factory, preview)
# GameMode.new_session() -> ModeSession
# GameMode.preview(observation, context) -> ModeSnapshot
# ModeRegistry(definitions: Sequence[GameMode])
# ModeRegistry.get(mode_id: str) -> GameMode
# ModeRegistry.metadata() -> tuple[ModeMetadata, ...]
# validate_snapshot(snapshot: object) -> ModeSnapshot  # raises ValueError
# BUILTIN_MODES: ModeRegistry, registry order full/half/quarter
```

`ModeMetadata` is a frozen value with `id`, `label`, `description`, and `required_port_count: int | None`. Session methods receive actual elapsed nanoseconds from the race start. Field modes ignore elapsed time; timed fixtures do not. `preview` is a pure callable, not a retained session.

Controller API additions: `observe_board(player_number, values)`, `select_mode(mode_id)`, `set_verification(verify)`, `leaderboard_activity(race_id)`, `capture_browse(mode_id, race_id)`, `browse_is_current(origin)`, and `set_persistence(origin, error)`. All public mutations return `StateChange`. Keep existing start/space/reset/manual-stop/name APIs. Inject `registry=BUILTIN_MODES` into `RaceStateMachine` and `create_app` for fixtures.

`RaceOrigin(race_id: str, mode_id: str)` accompanies every leaderboard transition, including empty submissions. Add `mode_id: str` to `ScoreSubmission` and `NewLeaderboardEntry`; use keyword construction to avoid positional mistakes. `StateChange` gains `origin: RaceOrigin | None` and `diagnostic: str | None`. Diagnostics are formatted exception details collected during evaluation; runtime logs them after lock release.

`BrowseOrigin(epoch: int, phase: Phase, mode_id: str, race_id: str | None)` captures eligibility under the controller lock. Increment `epoch` on start, reset, selection, and entry into a new view-owning phase, not on ordinary ticks/observations. It invalidates slow reads even across ready -> racing -> reset -> ready. `browse_is_current` processes expiry and checks every origin field; runtime must publish an expiry transition if that check expires the race.

The shared `game_state` payload retains existing timing/name fields and adds:

```json
{
  "revision": 1,
  "mode": {"id": "quarter-field", "label": "Quarter Field", "description": "Patch the leftmost six columns.", "required_port_count": 12},
  "available_modes": [],
  "mode_error": null,
  "persistence_status": "idle",
  "players": {"1": {"presentation": {"objective": "Patch the leftmost six columns.", "stage": null, "progress": {"current": 0, "total": 12, "unit": "correct"}, "ports": [], "complete": false, "led_intent": null}}}
}
```

The abbreviated arrays in this payload example are filled with registry metadata and exactly 48 port presentations in production. Include player 2 and existing player clock fields. `persistence_status` is `idle`, `pending`, `saved`, or `error`. Remove shared `leaderboard` row collections. Increment a monotonic controller `revision` for published state changes; browsers ignore older revisions so outside-lock emits cannot roll back UI state. Reconnect establishes a new revision baseline to support server restart.

### Visual Contract

Preserve the paper background, ridged blue frame, black outlines, offset shadows, existing blue/red/yellow/green/pink palette, condensed bold headings, monospaced timers, humorous existing copy, and current animations. Do not modernize the UI into neutral cards, add a new icon/font package, or reformat unrelated CSS.

Extend `.idle-actions` into an in-flow `.mode-bar`, not a fixed overlay. At 1920x1080 it is a compact single row: current mode/count and a short description on the left, existing yellow button treatment and contextual key hints on the right. Keep at least 44px control targets. Wrap the bar at narrow widths; do not reduce the number of columns or obscure port numbers to make room.

Ready: mode control with `M: mode`, existing `L: leaderboard`, and `Space: start`. Racing: read-only current mode and `Space: stop`. Stopped: read-only current mode, `L: leaderboard`, and `Space: reset`. Name entry and leaderboards retain their own footer layout and gain a compact mode label; do not add duplicate shortcut bars. Selector hints are `Arrows: browse`, `Enter: select`, `Esc / M: cancel`. Never advertise unavailable actions.

The selector is a native `<dialog>` with a label, ordinary full-width option buttons, and a visible close button. Reuse existing paper/yellow surfaces, 4px black borders, 5px offset shadows, and font variables. No new menu animation. Selected marker and visible focus outline are distinct; selection highlighting must not substitute for focus. Dialog options show label and description; the bar shows the authoritative selection, not the locally focused option.

## Task 1: Raw Board Model and Validation

**Files:** Create `Test_Server/board.py`, `Test_Server/tests/test_board.py`.

**Consumes:** Existing `EXPECTED_IDS` generation in `app.py` and canonical grid mapping in `index.html`.
**Produces:** `GameBoard`, `BoardObservation`, `EXPECTED_IDS`, `OPEN_ID`, `NUM_PORTS`, coordinate helpers.

- [ ] Add these focused failing tests, then parameterize invalid input over lengths 47/49, booleans, floats, strings, -1, and 256. Check both coordinate boundaries and every valid round trip.

```python
import pytest
from board import GameBoard, EXPECTED_IDS, coordinates, port_index

def test_invalid_frame_keeps_previous_raw_observation():
    board = GameBoard()
    assert board.snapshot().identities is None
    accepted = board.update(EXPECTED_IDS)
    with pytest.raises(ValueError):
        board.update([True] * 48)
    assert board.snapshot() == accepted
    assert accepted.identities == EXPECTED_IDS

def test_layout_alternates_top_and_bottom():
    for index in range(48):
        assert coordinates(index) == (index // 2, index % 2)
        assert port_index(*coordinates(index)) == index
```

- [ ] Run `uv run pytest tests/test_board.py -q`; expect import failure before implementation.
- [ ] Implement the cache and strict validation. Move the expected-ID expression without changing its values; freeze it as a tuple. Coordinate helpers reject non-integer/bool and out-of-range arguments with `ValueError`.

```python
from dataclasses import dataclass

@dataclass(frozen=True)
class BoardObservation:
    identities: tuple[int, ...] | None

class GameBoard:
    def __init__(self):
        self._observation = BoardObservation(None)

    def snapshot(self):
        return self._observation

    def update(self, values):
        if not isinstance(values, (list, tuple)) or len(values) != 48:
            raise ValueError("expected 48 byte identities")
        if any(type(value) is not int or not 0 <= value <= 255 for value in values):
            raise ValueError("expected 48 byte identities")
        self._observation = BoardObservation(tuple(values))
        return self._observation
```

- [ ] Run `uv run pytest tests/test_board.py -q`; expect all tests passing. Check input-list mutation cannot mutate a published observation. Review this isolated domain change before continuing.

## Task 2: Session Contract, Registry, and Field Modes

**Files:** Create `Test_Server/gamemodes.py`, `Test_Server/tests/test_gamemodes.py`, `Test_Server/tests/mode_fixtures.py`.

**Consumes:** Task 1 immutable observations and constants.
**Produces:** All `gamemodes.py` contracts above, three registered modes, test-only staged/timed sessions.

- [ ] Write parameterized tests for `(full-field, 48)`, `(half-field, 24)`, `(quarter-field, 12)`. Include the following positive completion test plus required-open/wrong, arbitrary inactive identities, bypass, unknown board, and repeated pure-preview tests.

```python
import pytest
from board import GameBoard, EXPECTED_IDS
from gamemodes import BUILTIN_MODES, EvaluationContext

@pytest.mark.parametrize("mode_id,count", [("full-field", 48), ("half-field", 24), ("quarter-field", 12)])
def test_field_targets_and_prepatched_completion(mode_id, count):
    mode = BUILTIN_MODES.get(mode_id)
    board = GameBoard()
    observation = board.update(EXPECTED_IDS[:count] + (255,) * (48 - count))
    result = mode.new_session().initialize(observation, EvaluationContext(True), 0)
    assert result.complete
    assert result.progress.current == result.progress.total == count
    assert tuple(i for i, port in enumerate(result.ports) if port.required) == tuple(range(count))
```

- [ ] Run `uv run pytest tests/test_gamemodes.py -q`; expect missing module/API failures.
- [ ] Define frozen nested dataclasses and a `Protocol` for the three session methods. Implement one field evaluator shared by the factory's sessions and the pure preview. Use this feedback rule for every port, including inactive ones; only target members contribute to progress/completion.

```python
def feedback(value, expected, context):
    if value == 255:
        return "open"
    if not context.verify or value == expected:
        return "correct"
    return "wrong"

def evaluate_field(observation, context, count, objective):
    identities = observation.identities
    ports = tuple(
        PortPresentation(
            required=index < count,
            feedback="unknown" if identities is None else feedback(identities[index], EXPECTED_IDS[index], context),
        )
        for index in range(48)
    )
    correct = sum(port.required and port.feedback == "correct" for port in ports)
    return ModeSnapshot(objective, None, Progress(correct, count, "correct"), ports, identities is not None and correct == count)
```

- [ ] Implement `validate_snapshot` as the only acceptance gate for mode output: exact `ModeSnapshot` and nested value types; nonempty objective; optional string stage; optional `Progress` with exact integer current >=0 and total >0 and nonempty unit; exactly 48 ports with bool membership and one of `open/wrong/correct/unknown`; bool completion; optional tuple of exactly 48 `LedState` values with exact bool channels. Do not impose `current <= total`, which the spec does not require. Reject mutable nested lists. Distinguish `None` LED intent from an all-off frame.
- [ ] Validate registry definitions at construction: nonempty stable ID/label/description, unique ID, callable factory/preview, and optional positive integer port count. Unknown lookups reject cleanly. No discovery or imports of Flask, serial, SQLite, or clocks. Use descriptions `Patch all 24 columns.`, `Patch the leftmost 12 columns.`, and `Patch the leftmost six columns.`; factories always return a fresh object.
- [ ] Implement a test-only `StagedSession`: initialization starts stage `Patch` targeting port 0; correct raw identity at port 0 enters `Wait`, targeting port 1 and recording the elapsed time; ticks complete after 2_000_000_000 ns in `Wait` even with no further observations. Build snapshots with `dataclasses.replace` over a valid field preview. Assert two instances advance independently, input remains immutable, and preview never changes an instance. Add failing-factory, failing-preview, failing-observe/tick, and malformed-output fixtures.

```python
def test_led_absence_and_all_off_are_distinct(valid_snapshot):
    from dataclasses import replace
    from gamemodes import LedState, validate_snapshot
    assert validate_snapshot(valid_snapshot).led_intent is None
    explicit = replace(valid_snapshot, led_intent=(LedState(False, False),) * 48)
    assert validate_snapshot(explicit).led_intent == (LedState(False, False),) * 48
```

Define `valid_snapshot` as a pytest fixture returning Full Field's preview of `GameBoard().snapshot()` with `EvaluationContext(True)`.

- [ ] Run `uv run pytest tests/test_board.py tests/test_gamemodes.py -q`; expect pass. Review the contributor-facing API before wiring transport.

## Task 3: Authoritative Mode Lifecycle

**Files:** Modify `Test_Server/race.py`, `Test_Server/tests/test_race.py`; use `Test_Server/tests/mode_fixtures.py`.

**Consumes:** Board/session API from Tasks 1-2.
**Produces:** Controller additions, origin values, per-player presentations, mode metadata and error state, immutable completed-race submissions.

- [ ] Replace test `VERIFIED = [2] * 48` with `EXPECTED_IDS` and `observe_cells` calls with `observe_board`. Preserve existing name-entry/timing regression tests; update equality assertions to include presentations without weakening their existing clock assertions. Add this start contract:

```python
def test_prepatched_quarter_field_finishes_both_at_zero(clock):
    from board import EXPECTED_IDS
    machine = RaceStateMachine(clock_ns=clock)
    machine.select_mode("quarter-field")
    values = EXPECTED_IDS[:12] + (255,) * 36
    machine.observe_board(1, values)
    machine.observe_board(2, values)
    machine.start()
    state = machine.snapshot()
    assert state["phase"] == "name_entry"
    assert state["tie"] is True
    assert [state["players"][str(p)]["duration_ms"] for p in (1, 2)] == [0, 0]
    machine.reset()
    assert machine.snapshot()["mode"]["id"] == "quarter-field"
```

- [ ] Run `uv run pytest tests/test_race.py -q`; expect missing controller API failures.
- [ ] Initialize registry, selected ID, both `GameBoard`s, verification context, epoch, and revision once in `__init__`, outside `_reset_unlocked`. Reset only race-owned state and rebuild pure previews from retained observations. Save `race_mode_id` at start; never derive completed-race mode from later selection.
- [ ] Refactor internal transitions to receive one captured `now_ns`. In each start transition, create and initialize both sessions using the same `started_ns` and elapsed zero; validate both results before publishing completion. Stage output in local values first so a failure for player 2 cannot leave a partially accepted race. Enter name entry once after evaluating both players.

```python
now_ns = self._clock_ns()
elapsed_ns = max(0, now_ns - self.started_ns)
result = validate_snapshot(session.observe(observation, self.context, elapsed_ns))
```

Use that evaluation pattern inside the lock only; reuse it for initialize/tick with the appropriate method. Do not call a mode from `snapshot()`; snapshots copy already-validated presentation data. Call previews only on ready observation/selection/context changes or reset.
- [ ] Implement `observe_board` with validation and cache publication under the same lock as session delivery. Invalid inputs do not change the board or reach a session. Ready observations evaluate preview. Racing observations evaluate unfinished sessions even if individually stopped. Other phases retain physical observations without advancing sessions. Completed sessions keep their final presentation. On global stop, freeze presentations; reset reveals fresh previews of current physical observations.
- [ ] Evaluate unfinished sessions during racing `tick()` using actual elapsed time; return `changed=True` when objective, stage, targets, progress, feedback, or LED intent changes, even without a phase change. Latch first completion. Keep displayed diagnostic-stop duration frozen, but use original elapsed time for evaluation and allow completion to replace that stop. Stop evaluation on global stop or when both players have diagnostic stops. Preserve the existing case where one player is complete and the other individually stopped: the shared phase remains racing and the unfinished session can still complete.
- [ ] Keep verification state under the controller lock. `set_verification(bool)` updates context and reevaluates ready previews or unfinished racing sessions at one captured time; completed results remain latched. Runtime will no longer read a separate mutable verification flag.
- [ ] Assign `revision` under the controller lock on every accepted published mutation, including partial progress, physical observation publication, selection, verification, persistence status, and deadline refresh. Snapshot reads and clock-only countdown broadcasts do not increment it. Include current revision in both `game_state` and `clock_update`. Add tests for monotonicity across reset and equal revisions on repeated read-only snapshots.
- [ ] Catch factory, initialization, evaluation, and validation exceptions. A ready preview failure sets `mode_error`, blocks start, and leaves other selections usable. An active failure sets `Phase.STOPPED`, freezes clocks, discards sessions/submissions, and publishes a short recoverable error with reset available. Put formatted diagnostic details in the transition for outside-lock logging; do not expose tracebacks in UI. Reset clears the race error, then reports any new preview failure.
- [ ] Test all rejection/reset paths: unknown IDs and non-ready selection; explicit reset, stopped Space reset, dismissal, and automatic expiry preserve selection; startup returns to Full Field. Test factory freshness, stages, tick-only completion, exceptions on every method, unknown initial boards, individual/global stops, clock floor, and latching after unplugging. Use `threading.Event` barriers, not sleeps, to order observe/start/reset in both directions; each delivered observation belongs to the session current when its lock is acquired.
- [ ] Run `uv run pytest tests/test_race.py tests/test_gamemodes.py -q`; expect pass. Review locking and error paths independently before transport integration.

## Task 4: Per-Mode Migration and Snapshot Pagination

**Files:** Modify `Test_Server/leaderboard.py`, `Test_Server/tests/test_leaderboard.py`.

**Consumes:** Explicit immutable `mode_id` on submissions.
**Produces:** `LeaderboardStore.snapshot_boundary(mode_id) -> int`, `page_entries(mode_id, boundary, offset, limit=50) -> LeaderboardPage`, and `LeaderboardPage(rows: tuple[RankedLeaderboardEntry, ...], next_offset: int | None)`.

- [ ] Add a legacy-schema database fixture using literal pre-mode DDL and rows, not the new `SCHEMA`. Assert migration preserves IDs, names, times, timestamps, uniqueness, and assigns `full-field`; reopen twice. Include insertion failure and forced migration rollback tests.
- [ ] Add a 121-row mode dataset with ties across row 50, another mode with faster times, and concurrent inserts after the captured boundary. Assert ranks across pages equal ranks from the complete original snapshot, every ID occurs exactly once, and an empty boundary remains empty after inserts.

```python
def test_empty_snapshot_stays_empty(store):
    boundary = store.snapshot_boundary("quarter-field")
    assert boundary == 0
    store.insert_entries([NewLeaderboardEntry(race_id="later", player_number=1, name="Ada", duration_ms=1, mode_id="quarter-field")])
    page = store.page_entries("quarter-field", boundary, 0)
    assert page.rows == ()
    assert page.next_offset is None
```

- [ ] Run `uv run pytest tests/test_leaderboard.py -q`; expect missing mode/page interface failures.
- [ ] Replace initialization through `executescript` with explicit transaction statements: `BEGIN IMMEDIATE`, create table if missing, inspect `PRAGMA table_info(leaderboard_entries)`, conditionally add `mode_id TEXT NOT NULL DEFAULT 'full-field'`, then create index `(mode_id, duration_ms, created_at, id)`. Roll back on any exception. Do not rebuild IDs or drop the existing uniqueness constraint. Fresh schemas include `mode_id`; normal inserts always pass it explicitly.
- [ ] Validate new entry `mode_id` as a nonempty string without requiring current registry membership: durable old scoring identities must remain readable. Preserve existing score validation and idempotent `(race_id, player_number)` insertion semantics. Query `COALESCE(MAX(id), 0)` with the mode filter for opening boundaries.
- [ ] Execute the following parameterized query with `limit + 1` rows to derive `next_offset`; return at most `limit`. Validate boundary/offset with exact integer types and values >=0, limit with exact integer type and 1-50. Reject bools and invalid modes before SQL.

```sql
SELECT id, race_id, player_number, name, duration_ms, created_at, mode_id, rank
FROM (
    SELECT id, race_id, player_number, name, duration_ms, created_at, mode_id,
           RANK() OVER (ORDER BY duration_ms) AS rank
    FROM leaderboard_entries
    WHERE mode_id = ? AND id <= ?
)
ORDER BY duration_ms, created_at, id
LIMIT ? OFFSET ?
```

Define the dataclass field order to match this projection or map named SQLite row fields explicitly. Ranking uses only duration; deterministic display order also includes creation time and ID. Remove `top_entries` after all callers migrate in Task 5; do not retain an unfiltered fallback.
- [ ] Run `uv run pytest tests/test_leaderboard.py -q`; expect pass including repeat initialization, tie boundaries, offset beyond end, and invalid bounds. Review migration transaction behavior before wiring the real app.

## Task 5: Raw Transport, Persistence Origins, and Page Events

**Files:** Modify `Test_Server/app.py`, `Test_Server/race.py`, `Test_Server/tests/test_app.py`, `Test_Server/tests/test_race.py`, `Test_Server/tests/browser_harness.py`.

**Consumes:** Tasks 1-4 APIs.
**Produces:** Mode-aware transport and immutable operation origins, with no I/O inside the controller lock.

- [ ] Update app fixtures and fake stores to explicit `mode_id`, raw `EXPECTED_IDS`, and the new store methods. Replace assertions on `game_state.leaderboard` with targeted page response assertions. Write two-client tests for selection broadcast, reconnect presentation, and requester-only pages before handlers exist.
- [ ] Define page protocol using the existing event names to keep transport changes local:

```javascript
// Request opening page. Subsequent pages reuse the returned boundary.
socket.emit("request_leaderboard", {
    request_id: 1, mode_id: "quarter-field", race_id: null,
    boundary: null, offset: 0
});
// Targeted response shape:
const pageResponse = {
    request_id: 1, mode_id: "quarter-field", race_id: null,
    boundary: 123, offset: 0, next_offset: 50,
    rows: [], error: null
};
```

`race_id=null` is an idle view allowed in ready/stopped; a post-race request must match the active leaderboard race/mode and wait until `persistence_status` is `saved` or `error`. This prevents a snapshot opening before the race's inserts finish. An error response echoes correlation fields and the requested offset; initial boundary may remain null if boundary acquisition failed, allowing retry from opening. Page size is fixed at 50 at the socket boundary.
- [ ] Run `uv run pytest tests/test_app.py -q`; expect failing transport assertions.
- [ ] Extract `decode_serial_frame(line: bytes) -> tuple[int, ...]` in `app.py`: strict ASCII, exactly 48 hex byte tokens, no signs or Python integer prefixes, token grammar `[0-9A-Fa-f]{1,2}`, reverse once. Pass decoded raw values to `runtime.observe_board`, which delegates directly to the controller. Remove runtime board cache and precomputed-state reduction; keep any compatibility presentation event derived from controller snapshots only until all browser consumers switch in Task 6. Never preserve an authoritative second cache.

```python
def observe_board(self, player_number, values):
    self.handle_change(self.race.observe_board(player_number, values))
```

Update `/randomize` to generate actual open/correct/wrong raw identities and return current presentation state; `/toggle-verify` calls the locked context transition. Keep serial restart/start behavior unchanged. Test reversed wire order using a frame with distinct values, malformed ASCII/text, bad byte lengths/ranges, and partial frames. Mock serial writes and assert no host LED writes occur.
- [ ] Add `select_mode` Socket.IO event with `{mode_id}` and acknowledgement `{accepted, mode_id, error}`. On accepted selection broadcast state to all clients. On non-ready/unknown/malformed requests acknowledge rejection without changing state. Acknowledgement is needed so the dialog can close on confirmation of the already-selected mode, even if no state change occurs.
- [ ] Refactor `_persist_and_load` into `_persist(origin, submissions)`. Mark pending during the locked leaderboard transition; copy `RaceOrigin` regardless of whether submissions are empty. In `handle_change`, emit the leaderboard/pending snapshot before starting the potentially blocking insert, then insert mode-tagged entries outside the lock. Apply and emit `set_persistence(origin, error)` only after expiry processing and exact phase/race/mode checks. Do not capture `self.race.snapshot()["race_id"]` after a write and use it as the origin. Do not read rows as part of persistence. Highlight page rows by stored `race_id == origin.race_id`, not by current browser selection. Add a delayed-insert two-client test proving both see the pending leaderboard before the insert is released and reset remains responsive during that wait.
- [ ] Implement page request validation before reads: dict, positive safe integer request ID, exact nonnegative safe integer offset/boundary (not bool), registered requested mode matching selected/race mode, null boundary only with offset zero, string-or-null race ID matching the view. Cap values at JavaScript's safe integer maximum. Maintain at most one active browsing token per Socket.IO client `(request_id, origin, boundary)`; reject older request IDs and changed boundaries, require a newer ID for reopening, and clear on disconnect. Capture/recheck controller origin around outside-lock boundary/page reads; recheck the per-client token before targeted emit. Protect this small token map separately and never acquire its lock across a database call.
- [ ] Complete the server opening handshake explicitly: keep the opening token's boundary null while capturing the boundary and reading page zero outside locks. On successful read and origin recheck, atomically promote that same token to the captured integer boundary under the token-map lock only if its request ID/origin still match, then send page zero. On initial read failure leave the token boundary null for retry; never recapture a boundary for later pages. Add a Socket.IO test that opens, takes the returned boundary, successfully fetches offset 50 with that boundary, and rejects offset 100 with a changed boundary. Include empty boundary zero and request replacement during opening.
- [ ] Add `leaderboard_activity` event `{race_id}` and controller expiry-first deadline handling. Only the matching live leaderboard can refresh to `now + 60s`; either viewer may do so. Page reads, responses, persistence, reconnect, and broadcast never refresh it.

```python
def test_activity_cannot_revive_expired_leaderboard(clock):
    machine = completed_race(clock)
    race_id = machine.snapshot()["race_id"]
    machine.submit_name(race_id, 1, "")
    machine.submit_name(race_id, 2, "")
    clock.advance_ms(60_000)
    machine.leaderboard_activity(race_id)
    assert machine.snapshot()["phase"] == "ready"
```

- [ ] Add event-barrier tests that delay insert/page reads while another thread resets, starts a new race, changes mode, expires the old view, replaces the request, or disconnects. Verify completed writes retain original mode, but no late result modifies a replacement race or emits a stale page. A blocking fake store must allow concurrent `race.reset()` to finish, proving the lock is not held during I/O. Test unavailable initialization, insertion, boundary read, and page read independently; the next race must still start.
- [ ] Adapt the browser harness's completion endpoint to raw identities; add `POST /__test__/observe/<player>` accepting a JSON array and a reset fixture endpoint that resets both physical boards to unknown using a newly constructed test app/runtime or a test-only board reset helper. Do not place fixture endpoints in production `app.py`.
- [ ] Run `uv run pytest -q`; expect full backend suite passing. Review origin validation, lock ordering, and expiry processing before frontend work.

## Task 6: Generic Board Rendering and Matching Mode Bar

Acceptance evidence: `.superpowers/sdd/task-6-report.md` records matched-viewport screenshots, geometry, tests and review findings. Revision baselines reset before the server's initial state, which can precede the client connect callback.

**Files:** Modify `Test_Server/templates/index.html`, `Test_Server/tests/test_app.py`, `Test_Server/tests/browser_harness.py`.

**Consumes:** `game_state.mode`, registry metadata, player presentations, existing timers.
**Produces:** Mode-neutral live overview, mode identity on results, visible recoverable errors.

Browser checks in Tasks 6-9 are **manual/agent-driven acceptance**, not pytest browser regression tests. The repo has no browser test runner, and this plan does not silently introduce one. Record observed results and screenshot locations in task checkboxes during execution. Backend/domain coverage remains automated. Delegate browser operation to an `independent-execute` subagent which loads `agent-browser`; use a dedicated local target and a second labeled target for multi-viewer checks, not unrelated browser tabs.

After starting the harness in a managed process, the browser worker uses:

```bash
open -a "Brave Browser Beta" --args --remote-debugging-port=9222
agent-browser --cdp 9222 tab new --label gamemodes-a http://127.0.0.1:5001
agent-browser --cdp 9222 set viewport 1920 1080
agent-browser --cdp 9222 snapshot -i
agent-browser --cdp 9222 screenshot
agent-browser --cdp 9222 press m
agent-browser --cdp 9222 eval 'document.activeElement.dataset.modeId'
agent-browser --cdp 9222 press ArrowDown
agent-browser --cdp 9222 press Escape
```

Expected after Task 7: `m` opens the dialog and focuses the selected mode; Escape closes it without selecting the browsed option. Use page-local `eval --stdin` assertions for DOM identity and geometry; do not claim an automated suite from these commands. Capture page-local errors only, following the browser skill's shared-CDP privacy boundary. Stop the harness and close only the created test targets when acceptance is complete.

- [x] Start the local harness with `uv run python tests/browser_harness.py` and load agent-browser. Capture baseline screenshots at 1920x1080 and 1280x720 before edits, including ready, racing, name entry, and leaderboard. Keep screenshots outside tracked source. Record board row/column positions, fonts, and timer layout for comparison.
- [x] Manually check the browser after selecting Quarter Field through Socket.IO: each board has 48 cells, exactly 12 required, indices 0-11 required, and port 12 retains its number and raw feedback but is dimmed. Record the missing behavior before rendering changes. Test unknown before any observation and `M` as a literal name character.
- [x] Track `lastStateRevision` in the browser. Reset it to null on Socket.IO `connect`, invalidate old browsing requests, and accept the next full `game_state` as the reconnect baseline. After that, reject lower revisions but accept equal revisions for countdown refreshes. Ignore `clock_update` until baseline exists and unless race ID, phase, and revision match current state. Add a backend test capturing two snapshots and intentionally emitting newer then older; in browser acceptance, confirm presentation and selected mode cannot revert. Reconnect to a restarted harness to prove a lower fresh-server revision is accepted.
- [x] Change `updateBoard` to consume generic `presentation.ports`; preserve `createBoard` coordinate assignments, `fitBoardCells`, IDs, and existing open/wrong/correct CSS. Add only `.is-inactive` and `.is-unknown` styles. Keep readable numbers with an explicit muted foreground/background rather than fading the whole cell until illegible. Update accessible labels:

```javascript
cell.classList.toggle("is-inactive", !port.required);
cell.classList.toggle("is-unknown", port.feedback === "unknown");
cell.setAttribute("aria-label", `Port ${index}, ${port.required ? "required" : "not required"}, ${port.feedback}`);
```

Do not replay cell-pop on every periodic snapshot; compare previous semantic feedback. Target membership changes from keyboard selection update immediately without a new animation. Remove legacy `table_update` handling when controller presentations supply every state.
- [x] Render objective and optional stage in a small per-player line adjacent to the existing caption/stats, retaining existing humorous captions. Keep objectives visible in the short-height breakpoint where `.switch-caption` is hidden. Reuse the three stat boxes: current/total from server progress, per-second rate for a meaningful counter, remaining clamped to zero. Null progress displays `-` for counter/rate/remaining, not fabricated port counts. For cross-player summary/leader, compare only matching unit/total/stage; otherwise show `-` while preserving card dimensions. Never branch on a mode ID.
- [x] Extend the existing action region with a current-mode label/description, a ready-only `modeButton`, and contextual shortcut text. Keep the bar present in ready/racing/stopped so changing phase does not resize the boards just to hide controls. Reuse `.leaderboard-button` and its `kbd` treatment for the new button, while leaving the old leaderboard button behavior intact until Task 8. Add mode labels to name entry and leaderboard without altering result cards or name fields.

```css
.mode-bar { flex: 0 0 auto; display: flex; align-items: center; justify-content: space-between; gap: 12px; flex-wrap: wrap; }
.mode-bar__info { min-width: 0; font-family: var(--font-condensed); }
.mode-bar__actions { display: flex; align-items: center; gap: 12px; flex-wrap: wrap; }
.mode-control:focus-visible { outline: 4px solid var(--blue); outline-offset: 4px; }
```

- [x] Show `mode_error` using the existing error surface treatment with `role="alert"`; advertise reset for stopped errors, and leave ready mode selection available after preview errors. Starting a broken preview remains blocked server-side.
- [x] Re-run browser assertions, inspect 1920x1080 screenshots against baseline, then run `uv run pytest tests/test_app.py -q`. Confirm no unintended header, timer, typography, name-entry, or physical-grid changes. Do not run a whole-template formatter.

## Task 7: Local Modal Selection and Keyboard Ownership

Acceptance evidence: `.superpowers/sdd/task-7-report.md` records two-viewer keyboard/focus checks, acknowledgement generations, screenshots and review fixes.

**Files:** Modify `Test_Server/templates/index.html`, `Test_Server/tests/test_app.py`.

**Consumes:** Registry metadata, `select_mode` acknowledgement, current phase/mode.
**Produces:** Hidden-by-default accessible selection dialog and guarded shortcuts.

- [x] Record manual before/after browser checks for selected-option focus on open, arrows clamped at ends, Tab/Shift+Tab including close control, Escape/M cancel, Enter/click confirmation, and Space suppression. Use two dedicated browser targets to verify local visibility and authoritative shared selection.
- [x] Add dialog markup outside the phase views so `showModal()` makes background controls inert. Populate ordinary buttons once from metadata; update selected markers in place on external changes, never rebuild focused options on every state event.

```html
<dialog id="modeDialog" aria-labelledby="modeDialogTitle">
    <h2 id="modeDialogTitle">Game mode</h2>

    <p>Arrows: browse | Enter: select | Esc / M: cancel</p>
    <button id="closeModeDialog" class="leaderboard-button" type="button">Close</button>
</dialog>
```

Style the dialog with existing `--paper`, `--ink`, `--yellow`, and font variables, 4px black border and offset shadow, max-height constrained to viewport with internal overflow. Ordinary option buttons include `data-mode-id`, text label/description, and `aria-pressed` for the selected marker. The native dialog supplies modality; explicitly constrain Tab at its first/last focusable control if browser behavior does not keep focus inside.
- [x] Implement `openModeSelector()`, `closeModeSelector({restoreFocus=true}={})`, and `confirmMode(modeId)`. Opening is allowed only in ready with no open/pending idle leaderboard. Opening focuses the selected button. Cancel never emits selection. Confirmation captures a local dialog generation; disable duplicate confirmations while pending, then close only if that generation is still current and acknowledgement accepted. On rejected selection show the error while ready or close on external phase change. Clicking the selected mode is still a successful confirmation.
- [x] Put text-entry checks and local-overlay ownership before global shortcuts. Preserve name-entry Enter/Tab behavior. Do not intercept modifier shortcuts or input/textarea/select/contenteditable typing. While modal is open, consume Space, M, Escape, arrows, and prevent L/V/S or race controls from reaching background handlers. Tab visits all option buttons and close; arrows visit options only without wrap.

```javascript
function moveModeFocus(step) {
    const options = Array.from(document.querySelectorAll("#modeOptions button"));
    const index = options.indexOf(document.activeElement);
    if (index < 0) return;
    options[Math.max(0, Math.min(options.length - 1, index + step))]?.focus();
}
```

- [x] On any authoritative phase change close the selector without restoring focus to a hidden mode button. Focus the first unresolved name field, leaderboard heading, or overview heading (`tabindex="-1"`) as appropriate. On external selection while still ready, update only marker and overview presentation, preserving locally browsed focus. On normal cancel/confirm restore mode-control focus.
- [x] Verify with browser: open M, move to Quarter, cancel and inspect unchanged mode; reopen and confirm; verify other client updates; open while another client starts; type `M` in both name fields; inspect focus outline separately from selected marker; verify no background HTTP control calls. Run `uv run pytest tests/test_app.py -q` after updating limited markup assertions. Behavioral browser checks, not string assertions alone, are the acceptance gate.

## Task 8: Local Page Browsing, Focus, and Activity

Acceptance evidence: `.superpowers/sdd/task-8-report.md` records pagination, genuine input, deadlines, final screenshots and review. It also explains the bounded fresh-snapshot recovery for the backend's unpublished browse epoch; this is not automatic invalidation detection.

**Files:** Modify `Test_Server/templates/index.html`, `Test_Server/tests/browser_harness.py`, `Test_Server/tests/test_app.py`.

**Consumes:** Targeted page protocol, mode/race metadata, persistence state, activity event.
**Produces:** All-score browsing with retained DOM/focus and separate idle/post-race deadlines.

- [x] Seed 121 scores per field mode in the harness, with ties crossing page boundaries. Add harness-only flags for failing/delaying the next page, and a release endpoint to unblock a delayed read using `threading.Event`. Exercise those flags through browser-driven HTTP calls. Seed faster scores ahead of a new completed race so its highlight appears beyond page one.
- [x] Before implementation, demonstrate failure to reach row 51 and failure to retain a row DOM node across periodic `game_state`. Then test the new browser state contract:

```javascript
let browsing = null;
// Created on open, not on each countdown broadcast:
function newBrowsingState(requestId, modeId, raceId) {
    return {
        requestId, modeId, raceId, boundary: null, nextOffset: 0,
        pendingOffset: null, rows: new Map(), navigationIntent: null,
        focusGeneration: 0
    };
}
```

- [x] Replace the `Top 10` title with `Leaderboard` plus the visible selected/completed mode label. Place a visible close button before a labeled `.leaderboard-scroll` container, keep native table markup and existing column styling, then load-more/retry control after rows. Scope height/layout changes to the leaderboard so the scroll area flexes within the existing view; use `min-height:0; overflow:auto` and retain the external countdown footer. Do not let the kiosk page scroll at 1920x1080.
- [x] Implement `openLeaderboard`, `requestNextPage`, `appendLeaderboardPage`, and `closeLeaderboard` around the browser-local token. Open immediately into a loading state and focus the heading. Post-race open waits to fetch until persistence settles; a countdown tick cannot reopen a locally closed/replaced request. On a fresh Socket.IO connection reset request/revision baselines and reopen eligible post-race browsing as a new snapshot without extending the server deadline.
- [x] Request only one page at a time. The opening handshake is special: while local boundary is null and pending offset is zero, accept a matching request/mode/race/offset response with a nonnegative safe integer boundary and atomically adopt that boundary, including zero, before appending. On an opening read error, retain a null boundary and allow offset-zero retry. Later pages require exact equality with the adopted boundary as well as matching request/mode/race/expected offset. Test opening success, empty boundary zero, retry after opening failure, and rejection of a changed later boundary. Store row identity by database ID, append each `<tr tabindex="0">` once with `tableRow.dataset.scoreId = String(row.id)`, and preserve existing DOM nodes. Use `textContent` for names and descriptions. Remove empty/loading rows only when real rows arrive. Countdown/state handlers update labels/errors/deadline only, never call `replaceChildren()` on loaded rows.
- [x] Implement keyboard navigation with native Tab order intact. Down on heading enters first loaded score; Up/Down moves to adjacent loaded rows. At the last row with more data, request a page and retain focus. Enter on load-more/retry requests a page. Capture `{sourceElement, focusGeneration, requestId}` as navigation intent; a `focusin` increments generation. Move focus to the first appended row only if source focus and generation still match and the same view is open. Cancel stale intent on close/navigation away; do not resurrect it if the user later returns to the same element. Repeated keys during pending load must not create duplicate requests.
- [x] Prefetch near the loaded end (within five rows or one viewport), without changing focus or deadlines. On failure retain existing rows and initiating focus, announce error, and enable retry. At final row Down stays in place; Tab can reach controls. Row focus uses a blue outline distinct from yellow current-race highlighting. Never jump automatically to current-race rows.
- [x] Close local browsing on mode changes and non-idle phases. Preserve L/Escape dismissal in both views and Space dismissal only post-race. Local view and pending local open suppress race Space; M cannot open behind either. Selector prevents opening leaderboard behind it. Normal dismissal/expiry restores overview focus; external phase changes focus the appropriate new phase.
- [x] Implement `noteLeaderboardActivity()` with a local deadline refresh for idle and `{race_id}` emission for post-race. Count valid keyboard navigation, load-more/retry activation, and user scrolling; do not count countdowns, page responses, reconnect, `focus()` alone, or `scrollIntoView()` alone. Track wheel/touch/pointer scrollbar/key input intent before scroll events, and suppress programmatic scroll accounting; `scroll.isTrusted` alone cannot distinguish these. Throttle continuous input notifications to one per second with a trailing notification while still open, and clear timers/intents on close. Navigation triggering scroll counts once. Check local expiry before refreshing so a delayed input cannot revive an expired view.
- [x] Verify real browser behaviors: row 121 reachable by arrows and Tab; ties/highlights beyond page one; retained row identity/scroll through countdowns; page failure/retry; delayed append after focus moves away/back cannot steal focus; no duplicate pending loads; empty boundary stays empty after inserts; mode/race changes drop old responses; both viewers extend shared post-race deadline; only active local viewer extends idle deadline. Use the harness fake server clock for server expiry. For local idle acceptance, temporarily replace page-local `Date.now` with a controllable offset via `eval --stdin`, move it beyond the deadline, and invoke the same expiry-check function used by the countdown timer; reload the dedicated target afterward. Ensure the timer calls that expiry-check function, not just a fixed timeout. Do not change production timeout constants for tests.
- [x] Run `uv run pytest -q` and compare leaderboard screenshots with baseline for unchanged table typography, borders, time formatting, and highlight treatment. Review browser token lifecycle and inactivity sources independently.

## Task 9: Contributor Guide and Final Acceptance

**Files:** Create `docs/gamemode-authoring.md`; modify `README.md`; finalize affected tests only.

**Consumes:** Verified board/session/registry contracts and working built-in implementation.
**Produces:** Contributor entry point and a checked acceptance record in this plan.

- [x] Write a concise guide with the actual API signatures from `gamemodes.py`, registry insertion location, canonical index/coordinate layout, open identity 255 and unknown observations, explicit verification context, factory freshness, pure previews, initialize/observe/tick lifecycle, nanosecond elapsed time and one-second scheduling limitation, frozen output validation, optional LED intent, and durable scoring IDs. Link to built-in field evaluator and `tests/mode_fixtures.py` as static and stateful examples; do not add a fourth production mode.
- [x] Link the guide from README with an annotation rather than duplicating it:

```markdown
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

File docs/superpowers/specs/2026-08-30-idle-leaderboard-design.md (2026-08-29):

# Idle Leaderboard Design

## Goal

Make the existing top-10 leaderboard available while the kiosk is idle, display each entry's existing creation timestamp, and preserve the current race controls and ranking behavior.

## Scope

This change adds:

- A read-only idle leaderboard available in `ready` and `stopped`.
- A compact leaderboard control below the two player panels.
- `L` and `Escape` keyboard behavior plus a 60-second idle-view timeout.
- A `Set at` column based on the existing `created_at` value.
- `L` and `Escape` dismissal for the existing post-race leaderboard.

Starting remains unchanged. Cached cable state does not prevent `/start-clock` or Space from starting a ready game.

Leaderboard administration, deleting records, pagination, schema changes, and changing the top-10 ranking rules are out of scope.

## Architecture

The idle leaderboard is a client-local view backed by a targeted Socket.IO request. The server race phase remains `ready` or `stopped` while the view is open. A read-only screen therefore cannot participate in start, reset, completion, or post-race transitions.

The existing post-race leaderboard markup and row renderer are reused. The server reads through `LeaderboardStore.top_entries()` and emits results only to the requesting Socket.IO client.
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

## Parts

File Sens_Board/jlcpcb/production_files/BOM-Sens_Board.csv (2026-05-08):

Comment | Designator | Footprint | LCSC | Quantity
0 | R121,R122,R123,R124,R125,R126,R127,R128,R129,R130,R131,R132,R133,R134,R135 | R_0402_1005Metric | C17168 | 15
100n | C1,C103,C13,C2,C22,C3,C31,C4,C40,C49,C58,C67,C76,C85,C94 | C_0402_1005Metric | C1525 | 15
10k | R100,R101,R102,R103,R104,R105,R106,R107,R108,R109,R110,R111,R112,R113,R114,R115,R116,R117,R118,R119,R120,R25,R26,R27,R28,R29,R30,R31,R32,R33,R34,R35,R36,R37,R38,R39,R40,R41,R42,R43,R44,R45,R46,R47,R48,R49,R50,R51,R52,R53,R54,R55,R56,R57,R58,R59,R60,R61,R62,R63,R64,R65,R66,R67,R68,R69,R70,R71,R72,R73,R74,R75,R76,R77,R78,R79,R80,R81,R82,R83,R84,R85,R86,R87,R88,R89,R90,R91,R92,R93,R94,R95,R96,R97,R98,R99 | R_0402_1005Metric | C25744 | 96
120 | R1,R10,R11,R12,R13,R14,R15,R16,R17,R18,R19,R2,R20,R21,R22,R23,R24,R3,R4,R5,R6,R7,R8,R9 | R_0402_1005Metric | C25079 | 24
74HC165 | U10,U11,U12,U13,U14,U15,U4,U5,U6,U7,U8,U9 | SOIC-16_4.55x10.3mm_P1.27mm | C5613 | 12
74HC595 | U1,U2,U3 | SOIC-16_4.55x10.3mm_P1.27mm | C5947 | 3
Conn_01x09_Pin | J1,J2 | JST_PH_B9B-PH-SM4-TB_1x09-1MP_P2.00mm_Vertical | C2845458 | 2
~ | J3 | RJ45-TH_RJ45-TH_HC-RJ45-059D-2X6-2-04 | C46261622 | 1

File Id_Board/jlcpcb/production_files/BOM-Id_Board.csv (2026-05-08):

Comment | Designator | Footprint | LCSC | Quantity
0 | R10,R11,R15,R16,R18,R20,R21,R22,R23,R24,R4,R8 | R_0603_1608Metric | C21189 | 12
Conn_01x02_Pin | J2,J3 | JST_PH_B2B-PH-SM4-TB_1x02-1MP_P2.00mm_Vertical | C2936227 | 2
SW_DIP_x08 | SW1 | SW-SMD_16P-L20.3-W6.0-P2.54-LS9.3-BL | C5145016 | 1
~ | J1 | RJ45-TH_HC-WK88-H13-1X8-55QS_1 | C7501829 | 1

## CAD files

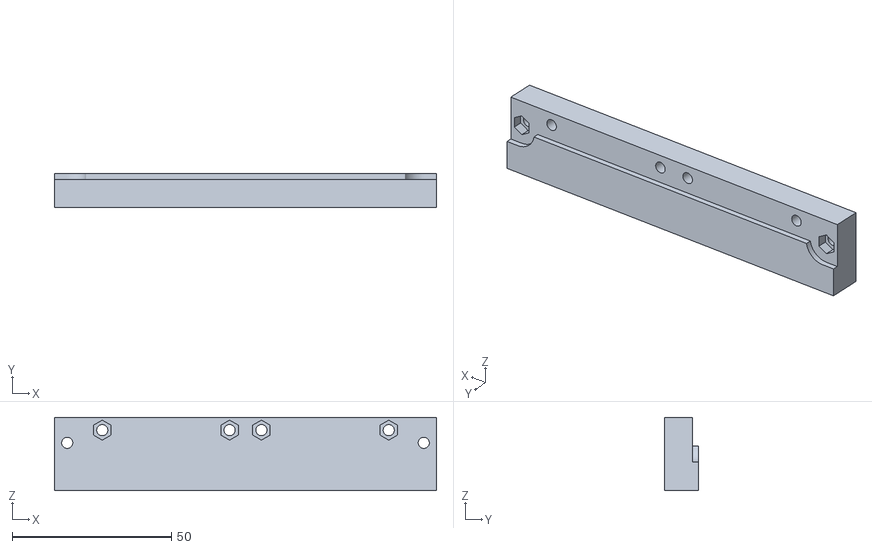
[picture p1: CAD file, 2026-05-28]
IDHolder.stl
120.0 x 10.6 x 23.0

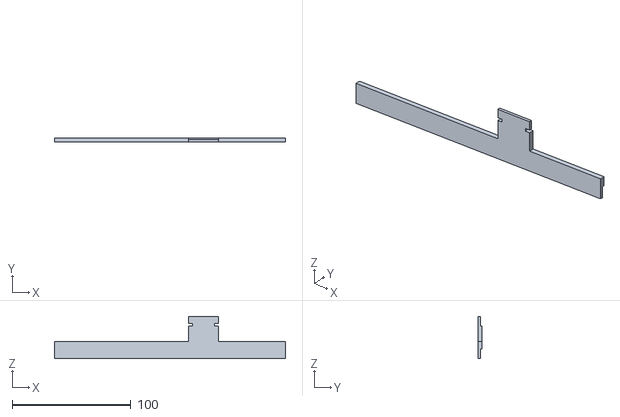
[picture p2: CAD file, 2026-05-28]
BlendePatchpannel1.stl
194.9 x 3.50 x 35.8

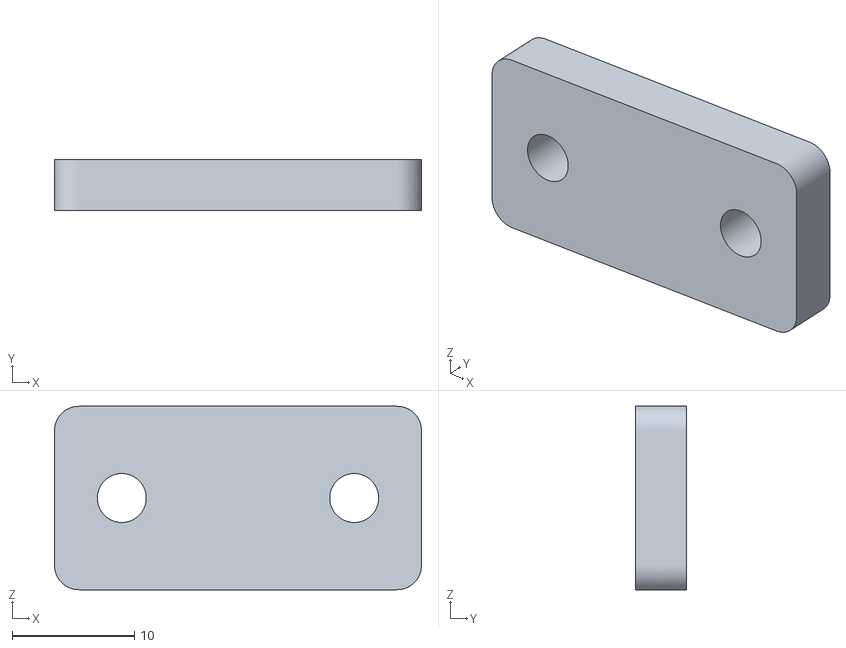
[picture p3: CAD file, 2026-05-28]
AbstandhalterSwitchPCB.stl
30.0 x 4.20 x 15.0

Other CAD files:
BlendePatchpannel2.stl

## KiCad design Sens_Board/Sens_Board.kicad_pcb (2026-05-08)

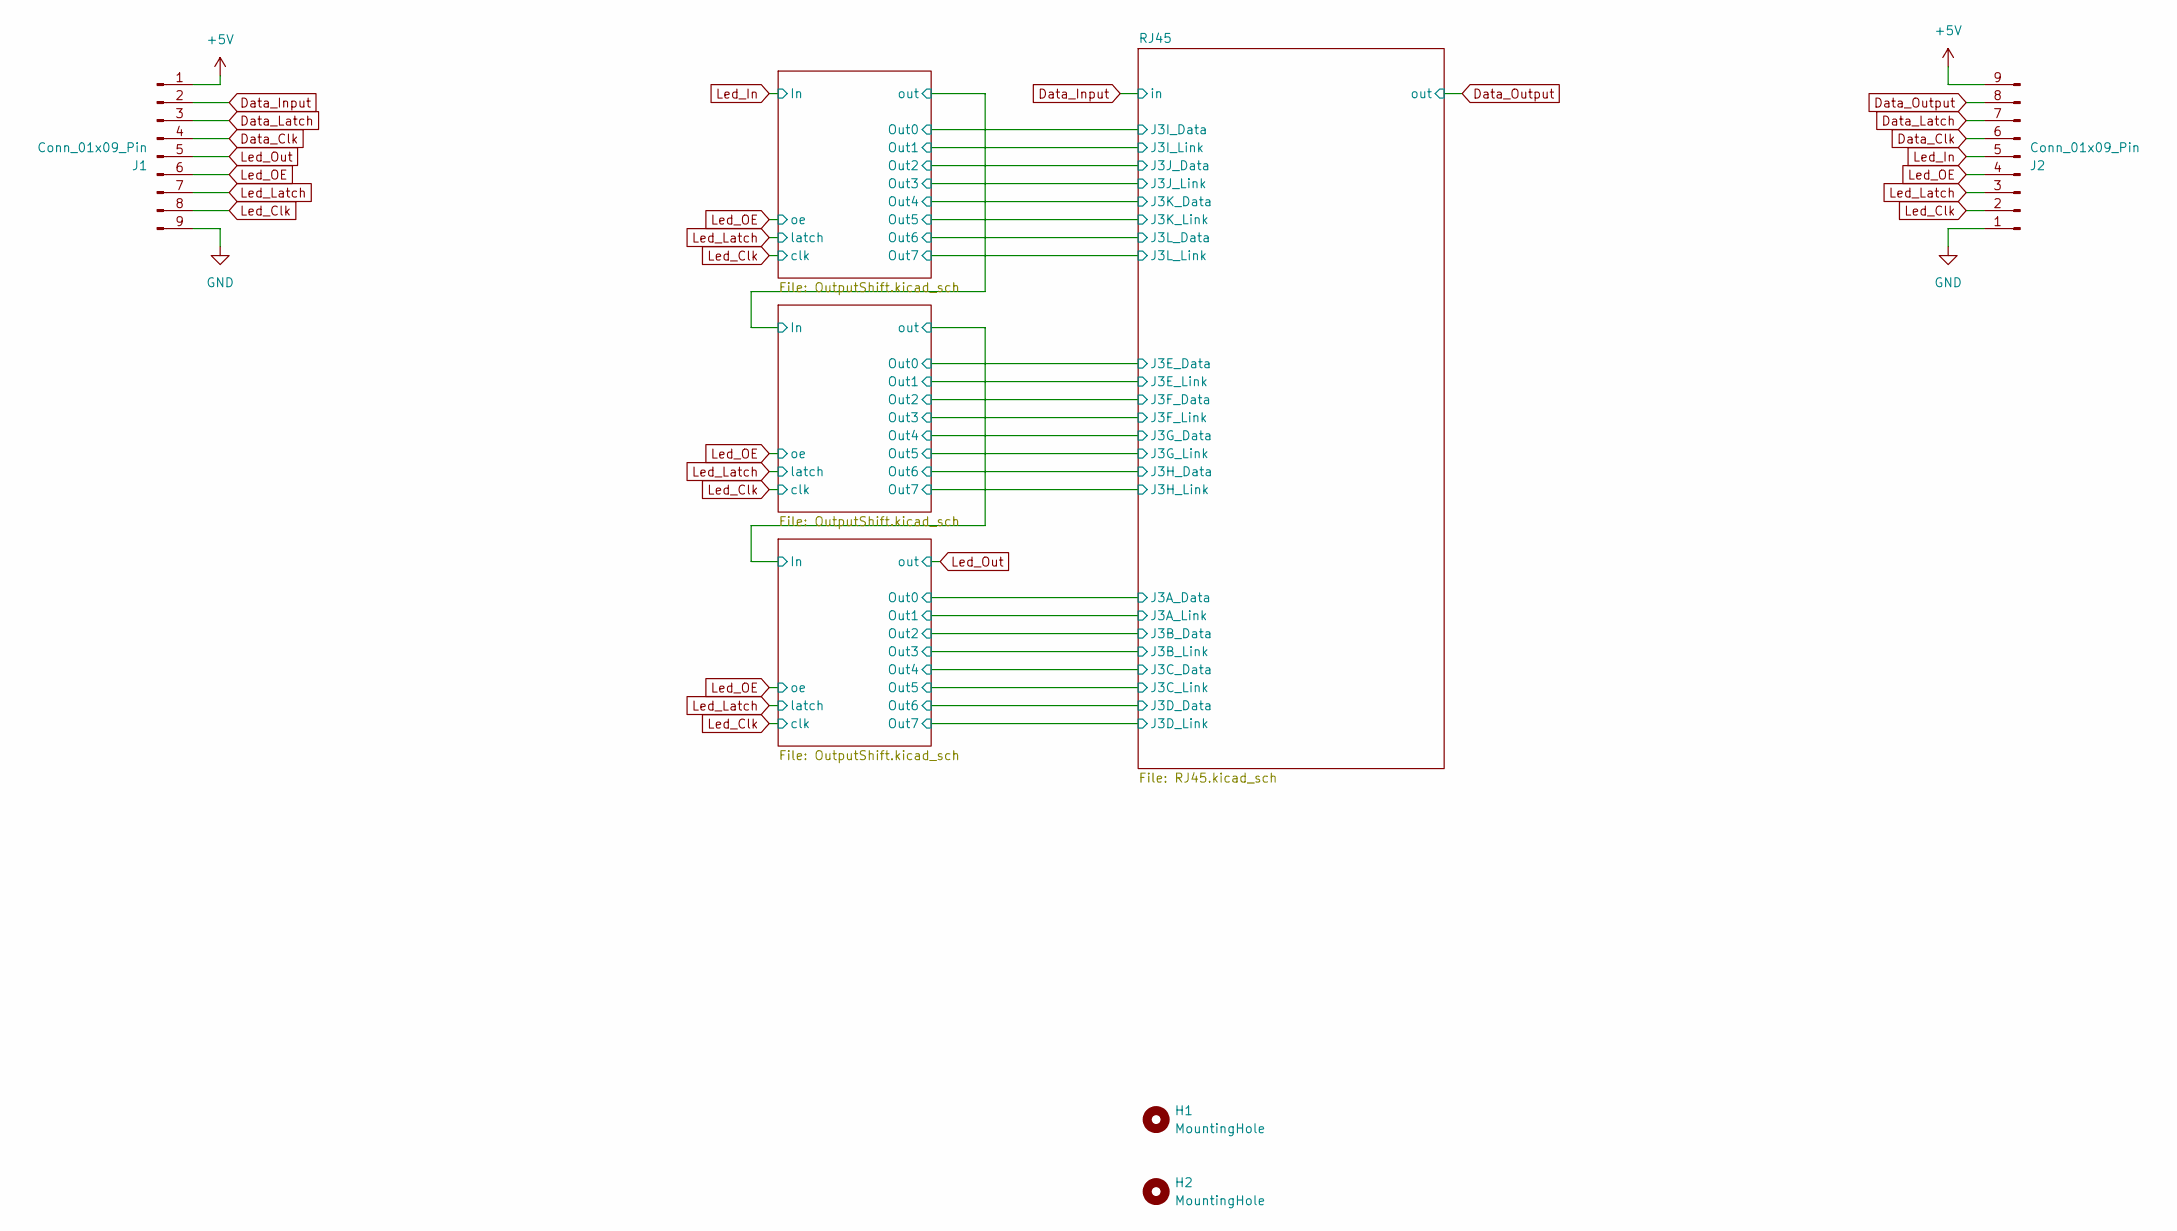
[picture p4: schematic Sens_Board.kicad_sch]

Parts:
H1, H2: MountingHole; MountingHole_3.2mm_M3
J1, J2: Conn_01x09_Pin; JST_PH_B9B-PH-SM4-TB_1x09-1MP_P2.00mm_Vertical

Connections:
+5V: J1.1, J2.9; also elsewhere on the board
Data_Clk: J1.4, J2.6; also elsewhere on the board
Data_Input: J1.2; also elsewhere on the board
Data_Latch: J1.3, J2.7; also elsewhere on the board
Data_Output: J2.8; also elsewhere on the board
GND: J1.9, J2.1; also elsewhere on the board
Led_Clk: J1.8, J2.2; also elsewhere on the board
Led_In: J2.5; also elsewhere on the board
Led_Latch: J1.7, J2.3; also elsewhere on the board
Led_OE: J1.6, J2.4; also elsewhere on the board
Led_Out: J1.5; also elsewhere on the board

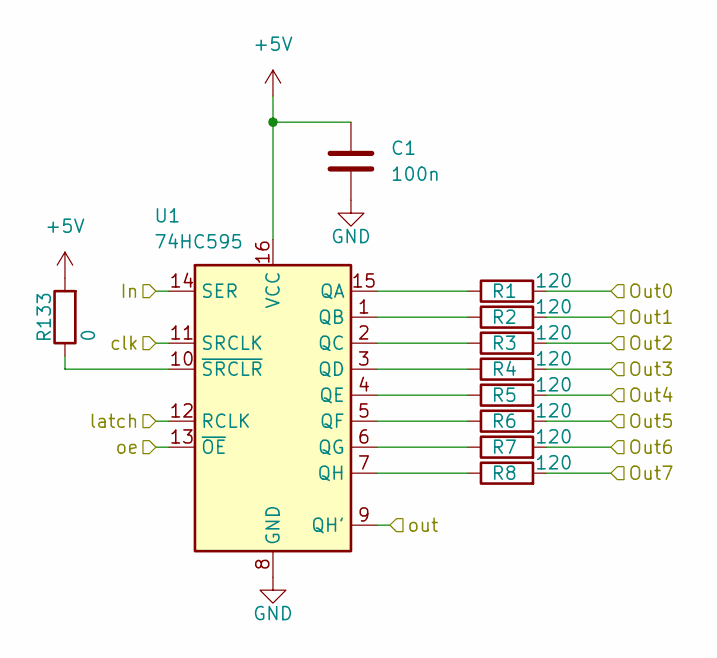
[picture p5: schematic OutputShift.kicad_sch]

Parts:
C1: 100n; C_0402_1005Metric
R1, R2, R3, R4, R5, R6, R7, R8: 120; R_0402_1005Metric
R133: 0; R_0402_1005Metric
U1: 74HC595; SOIC-16_4.55x10.3mm_P1.27mm

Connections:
+5V: C1.1, R133.2, U1.16 (VCC); also elsewhere on the board
/OutputShift1/Out0: R1.2; also elsewhere on the board
/OutputShift1/Out1: R2.2; also elsewhere on the board
/OutputShift1/Out2: R3.2; also elsewhere on the board
/OutputShift1/Out3: R4.2; also elsewhere on the board
/OutputShift1/Out4: R5.2; also elsewhere on the board
/OutputShift1/Out5: R6.2; also elsewhere on the board
/OutputShift1/Out6: R7.2; also elsewhere on the board
/OutputShift1/Out7: R8.2; also elsewhere on the board
/OutputShift1/out: U1.9 (QH'); also elsewhere on the board
/OutputShift/out: U1.14 (SER); also elsewhere on the board
GND: C1.2, U1.8 (GND); also elsewhere on the board
Led_Clk: U1.11 (SRCLK); also elsewhere on the board
Led_Latch: U1.12 (RCLK); also elsewhere on the board
Led_OE: U1.13 (~OE); also elsewhere on the board
unnamed: R1.1, U1.15 (QA)
unnamed: R2.1, U1.1 (QB)
unnamed: R3.1, U1.2 (QC)
unnamed: R4.1, U1.3 (QD)
unnamed: R5.1, U1.4 (QE)
unnamed: R6.1, U1.5 (QF)
unnamed: R7.1, U1.6 (QG)
unnamed: R8.1, U1.7 (QH)
unnamed: R133.1, U1.10 (~SRCLR)

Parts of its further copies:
C2, C3: 100n; C_0402_1005Metric
R9, R10, R11, R12, R13, R14, R15, R16, R17, R18, R19, R20, R21, R22, R23, R24: 120; R_0402_1005Metric
R134, R135: 0; R_0402_1005Metric
U2, U3: 74HC595; SOIC-16_4.55x10.3mm_P1.27mm

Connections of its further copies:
+5V: C2.1, C3.1, R134.2, R135.2, U2.16 (VCC), U3.16 (VCC); also elsewhere on the board
/OutputShift1/out: U3.14 (SER); also elsewhere on the board
/OutputShift2/Out0: R17.2; also elsewhere on the board
/OutputShift2/Out1: R18.2; also elsewhere on the board
/OutputShift2/Out2: R19.2; also elsewhere on the board
/OutputShift2/Out3: R20.2; also elsewhere on the board
/OutputShift2/Out4: R21.2; also elsewhere on the board
/OutputShift2/Out5: R22.2; also elsewhere on the board
/OutputShift2/Out6: R23.2; also elsewhere on the board
/OutputShift2/Out7: R24.2; also elsewhere on the board
/OutputShift/Out0: R9.2; also elsewhere on the board
/OutputShift/Out1: R10.2; also elsewhere on the board
/OutputShift/Out2: R11.2; also elsewhere on the board
/OutputShift/Out3: R12.2; also elsewhere on the board
/OutputShift/Out4: R13.2; also elsewhere on the board
/OutputShift/Out5: R14.2; also elsewhere on the board
/OutputShift/Out6: R15.2; also elsewhere on the board
/OutputShift/Out7: R16.2; also elsewhere on the board
/OutputShift/out: U2.9 (QH'); also elsewhere on the board
GND: C2.2, C3.2, U2.8 (GND), U3.8 (GND); also elsewhere on the board
Led_Clk: U2.11 (SRCLK), U3.11 (SRCLK); also elsewhere on the board
Led_In: U2.14 (SER); also elsewhere on the board
Led_Latch: U2.12 (RCLK), U3.12 (RCLK); also elsewhere on the board
Led_OE: U2.13 (~OE), U3.13 (~OE); also elsewhere on the board
Led_Out: U3.9 (QH'); also elsewhere on the board
unnamed: R9.1, U2.15 (QA)
unnamed: R10.1, U2.1 (QB)
unnamed: R11.1, U2.2 (QC)
unnamed: R12.1, U2.3 (QD)
unnamed: R13.1, U2.4 (QE)
unnamed: R14.1, U2.5 (QF)
unnamed: R15.1, U2.6 (QG)
unnamed: R16.1, U2.7 (QH)
unnamed: R134.1, U2.10 (~SRCLR)
unnamed: R17.1, U3.15 (QA)
unnamed: R18.1, U3.1 (QB)
unnamed: R19.1, U3.2 (QC)
unnamed: R20.1, U3.3 (QD)
unnamed: R21.1, U3.4 (QE)
unnamed: R22.1, U3.5 (QF)
unnamed: R23.1, U3.6 (QG)
unnamed: R24.1, U3.7 (QH)
unnamed: R135.1, U3.10 (~SRCLR)

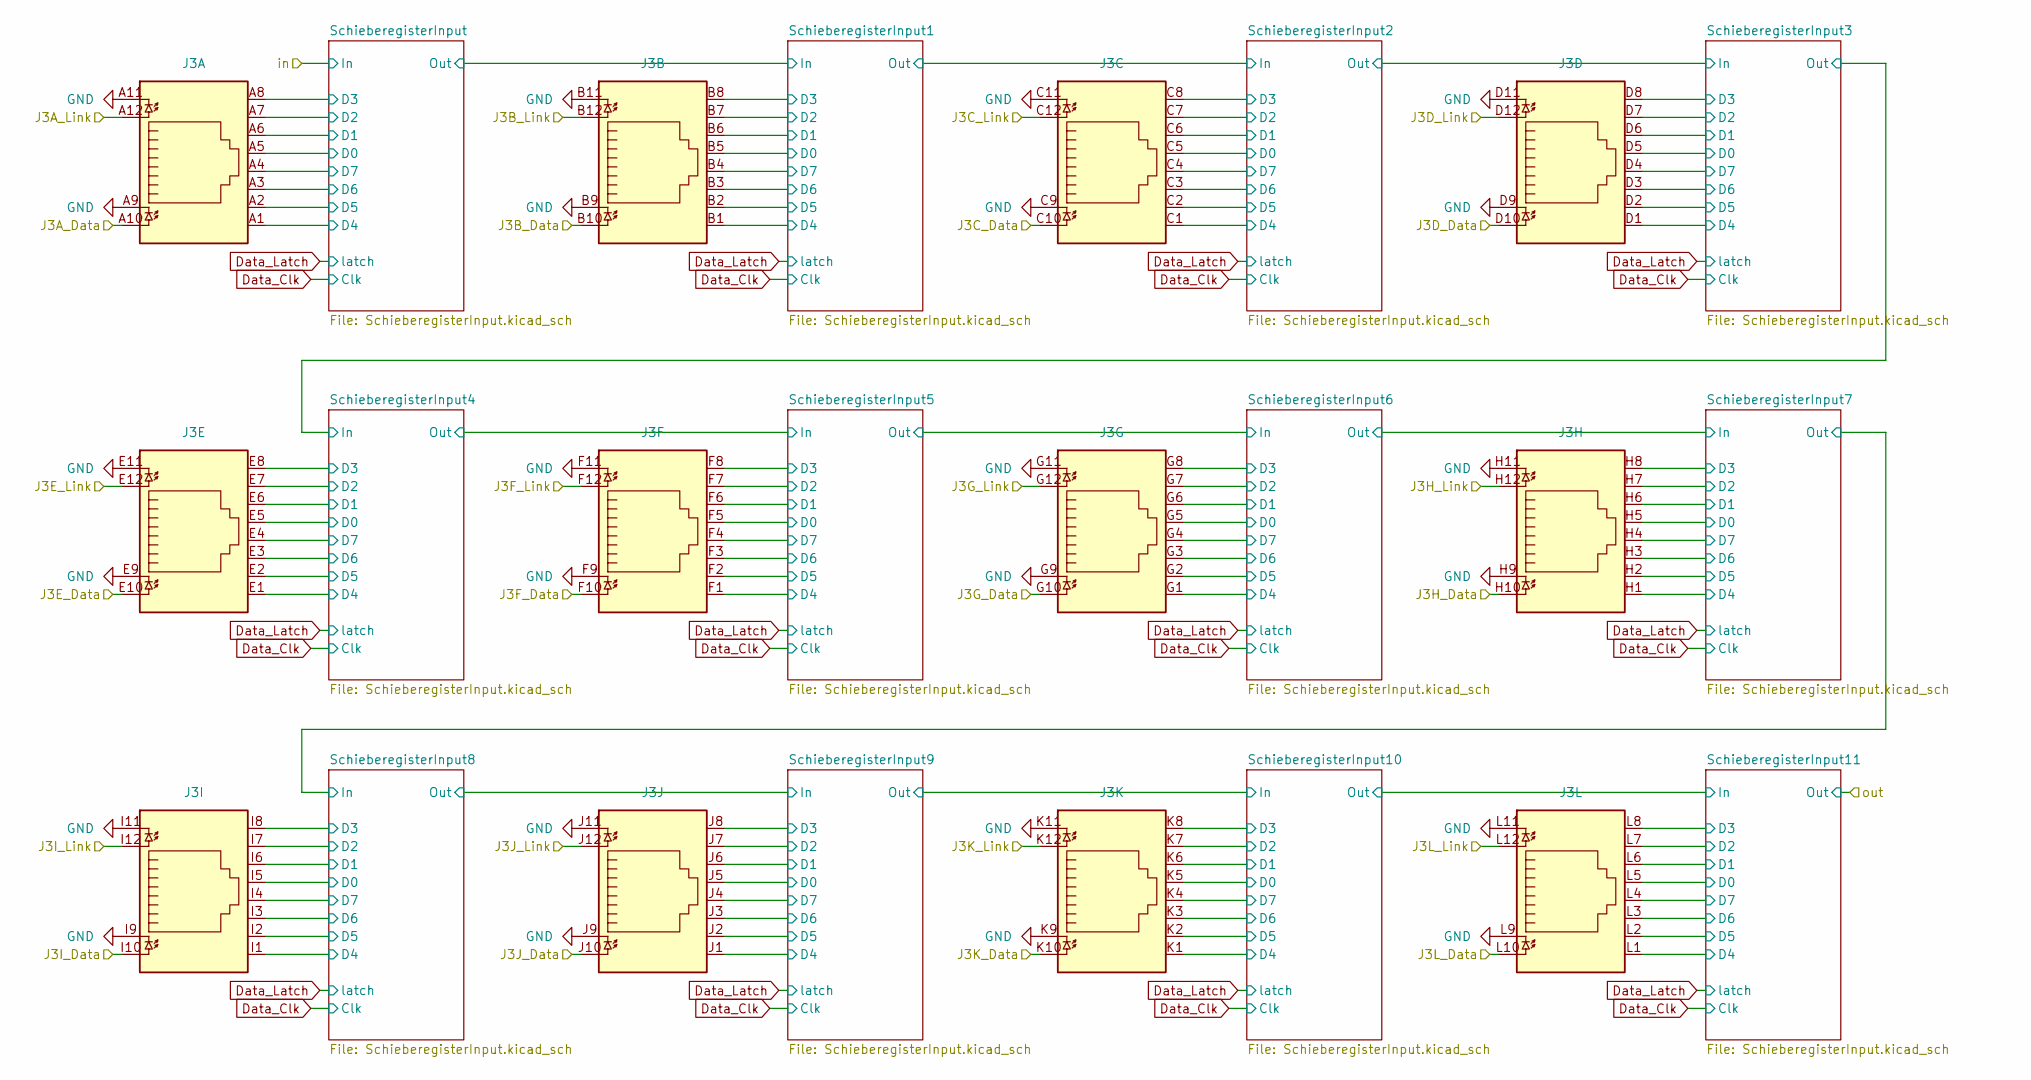
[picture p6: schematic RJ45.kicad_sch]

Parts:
J3: RJ45-TH_RJ45-TH_HC-RJ45-059D-2X6-2-04

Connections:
/OutputShift1/Out0: J3.E10; also elsewhere on the board
/OutputShift1/Out1: J3.E12; also elsewhere on the board
/OutputShift1/Out2: J3.F10; also elsewhere on the board
/OutputShift1/Out3: J3.F12; also elsewhere on the board
/OutputShift1/Out4: J3.G10; also elsewhere on the board
/OutputShift1/Out5: J3.G12; also elsewhere on the board
/OutputShift1/Out6: J3.H10; also elsewhere on the board
/OutputShift1/Out7: J3.H12; also elsewhere on the board
/OutputShift2/Out0: J3.A10; also elsewhere on the board
/OutputShift2/Out1: J3.A12; also elsewhere on the board
/OutputShift2/Out2: J3.B10; also elsewhere on the board
/OutputShift2/Out3: J3.B12; also elsewhere on the board
/OutputShift2/Out4: J3.C10; also elsewhere on the board
/OutputShift2/Out5: J3.C12; also elsewhere on the board
/OutputShift2/Out6: J3.D10; also elsewhere on the board
/OutputShift2/Out7: J3.D12; also elsewhere on the board
/OutputShift/Out0: J3.I10; also elsewhere on the board
/OutputShift/Out1: J3.I12; also elsewhere on the board
/OutputShift/Out2: J3.J10; also elsewhere on the board
/OutputShift/Out3: J3.J12; also elsewhere on the board
/OutputShift/Out4: J3.K10; also elsewhere on the board
/OutputShift/Out5: J3.K12; also elsewhere on the board
/OutputShift/Out6: J3.L10; also elsewhere on the board
/OutputShift/Out7: J3.L12; also elsewhere on the board
/RJ45/SchieberegisterInput1/D0: J3.B5; also elsewhere on the board
/RJ45/SchieberegisterInput1/D1: J3.B6; also elsewhere on the board
/RJ45/SchieberegisterInput1/D2: J3.B7; also elsewhere on the board
/RJ45/SchieberegisterInput1/D3: J3.B8; also elsewhere on the board
/RJ45/SchieberegisterInput1/D4: J3.B1; also elsewhere on the board
/RJ45/SchieberegisterInput1/D5: J3.B2; also elsewhere on the board
/RJ45/SchieberegisterInput1/D6: J3.B3; also elsewhere on the board
/RJ45/SchieberegisterInput1/D7: J3.B4; also elsewhere on the board
/RJ45/SchieberegisterInput2/D0: J3.C5; also elsewhere on the board
/RJ45/SchieberegisterInput2/D1: J3.C6; also elsewhere on the board
/RJ45/SchieberegisterInput2/D2: J3.C7; also elsewhere on the board
/RJ45/SchieberegisterInput2/D3: J3.C8; also elsewhere on the board
/RJ45/SchieberegisterInput2/D4: J3.C1; also elsewhere on the board
/RJ45/SchieberegisterInput2/D5: J3.C2; also elsewhere on the board
/RJ45/SchieberegisterInput2/D6: J3.C3; also elsewhere on the board
/RJ45/SchieberegisterInput2/D7: J3.C4; also elsewhere on the board
/RJ45/SchieberegisterInput3/D0: J3.D5; also elsewhere on the board
/RJ45/SchieberegisterInput3/D1: J3.D6; also elsewhere on the board
/RJ45/SchieberegisterInput3/D2: J3.D7; also elsewhere on the board
/RJ45/SchieberegisterInput3/D3: J3.D8; also elsewhere on the board
/RJ45/SchieberegisterInput3/D4: J3.D1; also elsewhere on the board
/RJ45/SchieberegisterInput3/D5: J3.D2; also elsewhere on the board
/RJ45/SchieberegisterInput3/D6: J3.D3; also elsewhere on the board
/RJ45/SchieberegisterInput3/D7: J3.D4; also elsewhere on the board
/RJ45/SchieberegisterInput4/D0: J3.E5; also elsewhere on the board
/RJ45/SchieberegisterInput4/D1: J3.E6; also elsewhere on the board
/RJ45/SchieberegisterInput4/D2: J3.E7; also elsewhere on the board
/RJ45/SchieberegisterInput4/D3: J3.E8; also elsewhere on the board
/RJ45/SchieberegisterInput4/D4: J3.E1; also elsewhere on the board
/RJ45/SchieberegisterInput4/D5: J3.E2; also elsewhere on the board
/RJ45/SchieberegisterInput4/D6: J3.E3; also elsewhere on the board
/RJ45/SchieberegisterInput4/D7: J3.E4; also elsewhere on the board
/RJ45/SchieberegisterInput5/D0: J3.F5; also elsewhere on the board
/RJ45/SchieberegisterInput5/D1: J3.F6; also elsewhere on the board
/RJ45/SchieberegisterInput5/D2: J3.F7; also elsewhere on the board
/RJ45/SchieberegisterInput5/D3: J3.F8; also elsewhere on the board
/RJ45/SchieberegisterInput5/D4: J3.F1; also elsewhere on the board
/RJ45/SchieberegisterInput5/D5: J3.F2; also elsewhere on the board
/RJ45/SchieberegisterInput5/D6: J3.F3; also elsewhere on the board
/RJ45/SchieberegisterInput5/D7: J3.F4; also elsewhere on the board
/RJ45/SchieberegisterInput6/D0: J3.G5; also elsewhere on the board
/RJ45/SchieberegisterInput6/D1: J3.G6; also elsewhere on the board
/RJ45/SchieberegisterInput6/D2: J3.G7; also elsewhere on the board
/RJ45/SchieberegisterInput6/D3: J3.G8; also elsewhere on the board
/RJ45/SchieberegisterInput6/D4: J3.G1; also elsewhere on the board
/RJ45/SchieberegisterInput6/D5: J3.G2; also elsewhere on the board
/RJ45/SchieberegisterInput6/D6: J3.G3; also elsewhere on the board
/RJ45/SchieberegisterInput6/D7: J3.G4; also elsewhere on the board
/RJ45/SchieberegisterInput7/D0: J3.H5; also elsewhere on the board
/RJ45/SchieberegisterInput7/D1: J3.H6; also elsewhere on the board
/RJ45/SchieberegisterInput7/D2: J3.H7; also elsewhere on the board
/RJ45/SchieberegisterInput7/D3: J3.H8; also elsewhere on the board
/RJ45/SchieberegisterInput7/D4: J3.H1; also elsewhere on the board
/RJ45/SchieberegisterInput7/D5: J3.H2; also elsewhere on the board
/RJ45/SchieberegisterInput7/D6: J3.H3; also elsewhere on the board
/RJ45/SchieberegisterInput7/D7: J3.H4; also elsewhere on the board
/RJ45/SchieberegisterInput8/D0: J3.I5; also elsewhere on the board
/RJ45/SchieberegisterInput8/D1: J3.I6; also elsewhere on the board
/RJ45/SchieberegisterInput8/D2: J3.I7; also elsewhere on the board
/RJ45/SchieberegisterInput8/D3: J3.I8; also elsewhere on the board
/RJ45/SchieberegisterInput8/D4: J3.I1; also elsewhere on the board
/RJ45/SchieberegisterInput8/D5: J3.I2; also elsewhere on the board
/RJ45/SchieberegisterInput8/D6: J3.I3; also elsewhere on the board
/RJ45/SchieberegisterInput8/D7: J3.I4; also elsewhere on the board
/RJ45/SchieberegisterInput9/D0: J3.J5; also elsewhere on the board
/RJ45/SchieberegisterInput9/D1: J3.J6; also elsewhere on the board
/RJ45/SchieberegisterInput9/D2: J3.J7; also elsewhere on the board
/RJ45/SchieberegisterInput9/D3: J3.J8; also elsewhere on the board
/RJ45/SchieberegisterInput9/D4: J3.J1; also elsewhere on the board
/RJ45/SchieberegisterInput9/D5: J3.J2; also elsewhere on the board
/RJ45/SchieberegisterInput9/D6: J3.J3; also elsewhere on the board
/RJ45/SchieberegisterInput9/D7: J3.J4; also elsewhere on the board
/RJ45/SchieberegisterInput10/D0: J3.K5; also elsewhere on the board
/RJ45/SchieberegisterInput10/D1: J3.K6; also elsewhere on the board
/RJ45/SchieberegisterInput10/D2: J3.K7; also elsewhere on the board
/RJ45/SchieberegisterInput10/D3: J3.K8; also elsewhere on the board
/RJ45/SchieberegisterInput10/D4: J3.K1; also elsewhere on the board
/RJ45/SchieberegisterInput10/D5: J3.K2; also elsewhere on the board
/RJ45/SchieberegisterInput10/D6: J3.K3; also elsewhere on the board
/RJ45/SchieberegisterInput10/D7: J3.K4; also elsewhere on the board
/RJ45/SchieberegisterInput11/D0: J3.L5; also elsewhere on the board
/RJ45/SchieberegisterInput11/D1: J3.L6; also elsewhere on the board
/RJ45/SchieberegisterInput11/D2: J3.L7; also elsewhere on the board
/RJ45/SchieberegisterInput11/D3: J3.L8; also elsewhere on the board
/RJ45/SchieberegisterInput11/D4: J3.L1; also elsewhere on the board
/RJ45/SchieberegisterInput11/D5: J3.L2; also elsewhere on the board
/RJ45/SchieberegisterInput11/D6: J3.L3; also elsewhere on the board
/RJ45/SchieberegisterInput11/D7: J3.L4; also elsewhere on the board
/RJ45/SchieberegisterInput/D0: J3.A5; also elsewhere on the board
/RJ45/SchieberegisterInput/D1: J3.A6; also elsewhere on the board
/RJ45/SchieberegisterInput/D2: J3.A7; also elsewhere on the board
/RJ45/SchieberegisterInput/D3: J3.A8; also elsewhere on the board
/RJ45/SchieberegisterInput/D4: J3.A1; also elsewhere on the board
/RJ45/SchieberegisterInput/D5: J3.A2; also elsewhere on the board
/RJ45/SchieberegisterInput/D6: J3.A3; also elsewhere on the board
/RJ45/SchieberegisterInput/D7: J3.A4; also elsewhere on the board
GND: J3.A9, J3.A11, J3.B9, J3.B11, J3.C9, J3.C11, J3.D9, J3.D11, J3.E9, J3.E11, J3.F9, J3.F11, J3.G9, J3.G11, J3.H9, J3.H11, J3.I9, J3.I11, J3.J9, J3.J11, J3.K9, J3.K11, J3.L9, J3.L11; also elsewhere on the board

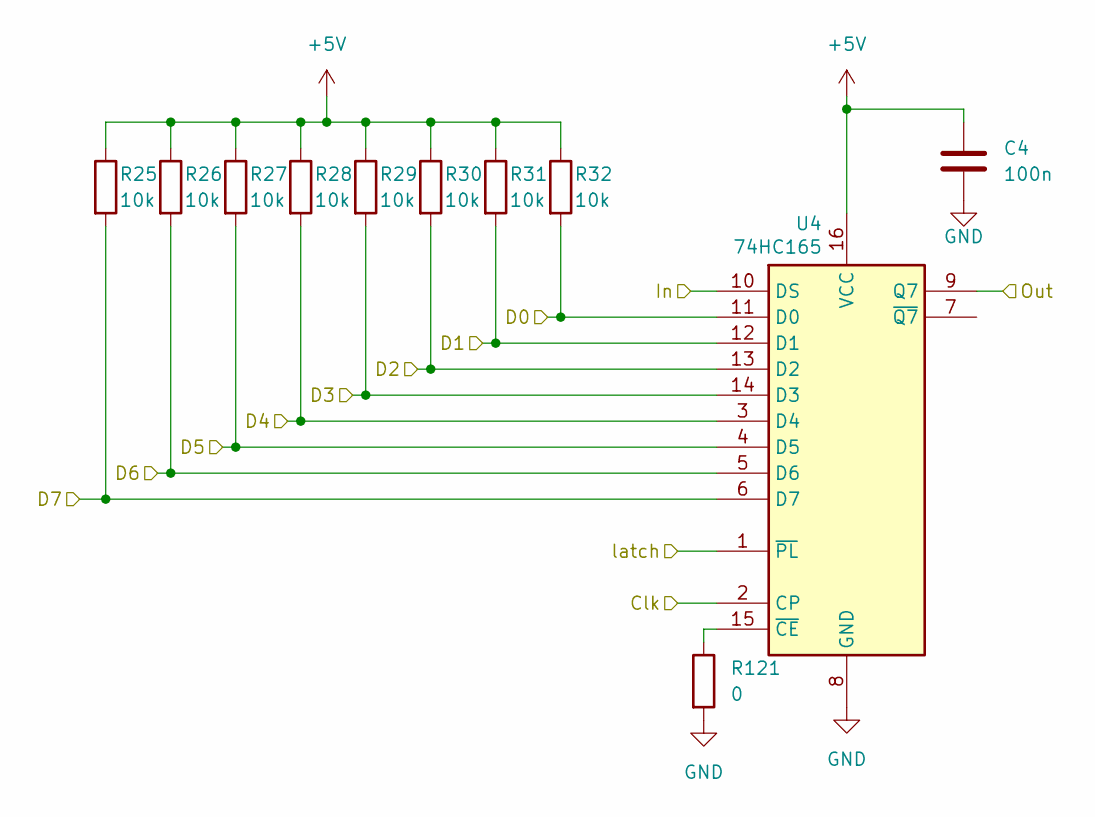
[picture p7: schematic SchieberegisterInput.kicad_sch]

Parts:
C4: 100n; C_0402_1005Metric
R25, R26, R27, R28, R29, R30, R31, R32: 10k; R_0402_1005Metric
R121: 0; R_0402_1005Metric
U4: 74HC165; SOIC-16_4.55x10.3mm_P1.27mm

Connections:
+5V: C4.1, R25.1, R26.1, R27.1, R28.1, R29.1, R30.1, R31.1, R32.1, U4.16 (VCC); also elsewhere on the board
/RJ45/SchieberegisterInput/D0: R32.2, U4.11 (D0); also elsewhere on the board
/RJ45/SchieberegisterInput/D1: R31.2, U4.12 (D1); also elsewhere on the board
/RJ45/SchieberegisterInput/D2: R30.2, U4.13 (D2); also elsewhere on the board
/RJ45/SchieberegisterInput/D3: R29.2, U4.14 (D3); also elsewhere on the board
/RJ45/SchieberegisterInput/D4: R28.2, U4.3 (D4); also elsewhere on the board
/RJ45/SchieberegisterInput/D5: R27.2, U4.4 (D5); also elsewhere on the board
/RJ45/SchieberegisterInput/D6: R26.2, U4.5 (D6); also elsewhere on the board
/RJ45/SchieberegisterInput/D7: R25.2, U4.6 (D7); also elsewhere on the board
/RJ45/SchieberegisterInput/Out: U4.9 (Q7); also elsewhere on the board
Data_Clk: U4.2 (CP); also elsewhere on the board
Data_Input: U4.10 (DS); also elsewhere on the board
Data_Latch: U4.1 (~PL); also elsewhere on the board
GND: C4.2, R121.2, U4.8 (GND); also elsewhere on the board
unnamed: R121.1, U4.15 (~CE)

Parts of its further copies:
C13, C22, C31, C40, C49, C58, C67, C76, C85, C94, C103: 100n; C_0402_1005Metric
R33, R34, R35, R36, R37, R38, R39, R40, R41, R42, R43, R44, R45, R46, R47, R48, R49, R50, R51, R52, R53, R54, R55, R56, R57, R58, R59, R60, R61, R62, R63, R64, R65, R66, R67, R68, R69, R70, R71, R72, R73, R74, R75, R76, R77, R78, R79, R80, R81, R82, R83, R84, R85, R86, R87, R88, R89, R90, R91, R92, R93, R94, R95, R96, R97, R98, R99, R100, R101, R102, R103, R104, R105, R106, R107, R108, R109, R110, R111, R112, R113, R114, R115, R116, R117, R118, R119, R120: 10k; R_0402_1005Metric
R122, R123, R124, R125, R126, R127, R128, R129, R130, R131, R132: 0; R_0402_1005Metric
U5, U6, U7, U8, U9, U10, U11, U12, U13, U14, U15: 74HC165; SOIC-16_4.55x10.3mm_P1.27mm

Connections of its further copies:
+5V: C13.1, C22.1, C31.1, C40.1, C49.1, C58.1, C67.1, C76.1, C85.1, C94.1, C103.1, R33.1, R34.1, R35.1, R36.1, R37.1, R38.1, R39.1, R40.1, R41.1, R42.1, R43.1, R44.1, R45.1, R46.1, R47.1, R48.1, R49.1, R50.1, R51.1, R52.1, R53.1, R54.1, R55.1, R56.1, R57.1, R58.1, R59.1, R60.1, R61.1, R62.1, R63.1, R64.1, R65.1, R66.1, R67.1, R68.1, R69.1, R70.1, R71.1, R72.1, R73.1, R74.1, R75.1, R76.1, R77.1, R78.1, R79.1, R80.1, R81.1, R82.1, R83.1, R84.1, R85.1, R86.1, R87.1, R88.1, R89.1, R90.1, R91.1, R92.1, R93.1, R94.1, R95.1, R96.1, R97.1, R98.1, R99.1, R100.1, R101.1, R102.1, R103.1, R104.1, R105.1, R106.1, R107.1, R108.1, R109.1, R110.1, R111.1, R112.1, R113.1, R114.1, R115.1, R116.1, R117.1, R118.1, R119.1, R120.1, U5.16 (VCC), U6.16 (VCC), U7.16 (VCC), U8.16 (VCC), U9.16 (VCC), U10.16 (VCC), U11.16 (VCC), U12.16 (VCC), U13.16 (VCC), U14.16 (VCC), U15.16 (VCC); also elsewhere on the board
/RJ45/SchieberegisterInput1/D0: R48.2, U5.11 (D0); also elsewhere on the board
/RJ45/SchieberegisterInput1/D1: R47.2, U5.12 (D1); also elsewhere on the board
/RJ45/SchieberegisterInput1/D2: R46.2, U5.13 (D2); also elsewhere on the board
/RJ45/SchieberegisterInput1/D3: R45.2, U5.14 (D3); also elsewhere on the board
/RJ45/SchieberegisterInput1/D4: R44.2, U5.3 (D4); also elsewhere on the board
/RJ45/SchieberegisterInput1/D5: R43.2, U5.4 (D5); also elsewhere on the board
/RJ45/SchieberegisterInput1/D6: R42.2, U5.5 (D6); also elsewhere on the board
/RJ45/SchieberegisterInput1/D7: R41.2, U5.6 (D7); also elsewhere on the board
/RJ45/SchieberegisterInput1/Out: U5.9 (Q7), U6.10 (DS)
/RJ45/SchieberegisterInput2/D0: R40.2, U6.11 (D0); also elsewhere on the board
/RJ45/SchieberegisterInput2/D1: R39.2, U6.12 (D1); also elsewhere on the board
/RJ45/SchieberegisterInput2/D2: R38.2, U6.13 (D2); also elsewhere on the board
/RJ45/SchieberegisterInput2/D3: R37.2, U6.14 (D3); also elsewhere on the board
/RJ45/SchieberegisterInput2/D4: R36.2, U6.3 (D4); also elsewhere on the board
/RJ45/SchieberegisterInput2/D5: R35.2, U6.4 (D5); also elsewhere on the board
/RJ45/SchieberegisterInput2/D6: R34.2, U6.5 (D6); also elsewhere on the board
/RJ45/SchieberegisterInput2/D7: R33.2, U6.6 (D7); also elsewhere on the board
/RJ45/SchieberegisterInput2/Out: U6.9 (Q7), U7.10 (DS)
/RJ45/SchieberegisterInput3/D0: R56.2, U7.11 (D0); also elsewhere on the board
/RJ45/SchieberegisterInput3/D1: R55.2, U7.12 (D1); also elsewhere on the board
/RJ45/SchieberegisterInput3/D2: R54.2, U7.13 (D2); also elsewhere on the board
/RJ45/SchieberegisterInput3/D3: R53.2, U7.14 (D3); also elsewhere on the board
/RJ45/SchieberegisterInput3/D4: R52.2, U7.3 (D4); also elsewhere on the board
/RJ45/SchieberegisterInput3/D5: R51.2, U7.4 (D5); also elsewhere on the board
/RJ45/SchieberegisterInput3/D6: R50.2, U7.5 (D6); also elsewhere on the board
/RJ45/SchieberegisterInput3/D7: R49.2, U7.6 (D7); also elsewhere on the board
/RJ45/SchieberegisterInput3/Out: U7.9 (Q7), U8.10 (DS)
/RJ45/SchieberegisterInput4/D0: R64.2, U8.11 (D0); also elsewhere on the board
/RJ45/SchieberegisterInput4/D1: R63.2, U8.12 (D1); also elsewhere on the board
/RJ45/SchieberegisterInput4/D2: R62.2, U8.13 (D2); also elsewhere on the board
/RJ45/SchieberegisterInput4/D3: R61.2, U8.14 (D3); also elsewhere on the board
/RJ45/SchieberegisterInput4/D4: R60.2, U8.3 (D4); also elsewhere on the board
/RJ45/SchieberegisterInput4/D5: R59.2, U8.4 (D5); also elsewhere on the board
/RJ45/SchieberegisterInput4/D6: R58.2, U8.5 (D6); also elsewhere on the board
/RJ45/SchieberegisterInput4/D7: R57.2, U8.6 (D7); also elsewhere on the board
/RJ45/SchieberegisterInput4/Out: U8.9 (Q7), U9.10 (DS)
/RJ45/SchieberegisterInput5/D0: R72.2, U9.11 (D0); also elsewhere on the board
/RJ45/SchieberegisterInput5/D1: R71.2, U9.12 (D1); also elsewhere on the board
/RJ45/SchieberegisterInput5/D2: R70.2, U9.13 (D2); also elsewhere on the board
/RJ45/SchieberegisterInput5/D3: R69.2, U9.14 (D3); also elsewhere on the board
/RJ45/SchieberegisterInput5/D4: R68.2, U9.3 (D4); also elsewhere on the board
/RJ45/SchieberegisterInput5/D5: R67.2, U9.4 (D5); also elsewhere on the board
/RJ45/SchieberegisterInput5/D6: R66.2, U9.5 (D6); also elsewhere on the board
/RJ45/SchieberegisterInput5/D7: R65.2, U9.6 (D7); also elsewhere on the board
/RJ45/SchieberegisterInput5/Out: U9.9 (Q7), U10.10 (DS)
/RJ45/SchieberegisterInput6/D0: R80.2, U10.11 (D0); also elsewhere on the board
/RJ45/SchieberegisterInput6/D1: R79.2, U10.12 (D1); also elsewhere on the board
/RJ45/SchieberegisterInput6/D2: R78.2, U10.13 (D2); also elsewhere on the board
/RJ45/SchieberegisterInput6/D3: R77.2, U10.14 (D3); also elsewhere on the board
/RJ45/SchieberegisterInput6/D4: R76.2, U10.3 (D4); also elsewhere on the board
/RJ45/SchieberegisterInput6/D5: R75.2, U10.4 (D5); also elsewhere on the board
/RJ45/SchieberegisterInput6/D6: R74.2, U10.5 (D6); also elsewhere on the board
/RJ45/SchieberegisterInput6/D7: R73.2, U10.6 (D7); also elsewhere on the board
/RJ45/SchieberegisterInput6/Out: U10.9 (Q7), U11.10 (DS)
/RJ45/SchieberegisterInput7/D0: R88.2, U11.11 (D0); also elsewhere on the board
/RJ45/SchieberegisterInput7/D1: R87.2, U11.12 (D1); also elsewhere on the board
/RJ45/SchieberegisterInput7/D2: R86.2, U11.13 (D2); also elsewhere on the board
/RJ45/SchieberegisterInput7/D3: R85.2, U11.14 (D3); also elsewhere on the board
/RJ45/SchieberegisterInput7/D4: R84.2, U11.3 (D4); also elsewhere on the board
/RJ45/SchieberegisterInput7/D5: R83.2, U11.4 (D5); also elsewhere on the board
/RJ45/SchieberegisterInput7/D6: R82.2, U11.5 (D6); also elsewhere on the board
/RJ45/SchieberegisterInput7/D7: R81.2, U11.6 (D7); also elsewhere on the board
/RJ45/SchieberegisterInput7/Out: U11.9 (Q7), U12.10 (DS)
/RJ45/SchieberegisterInput8/D0: R96.2, U12.11 (D0); also elsewhere on the board
/RJ45/SchieberegisterInput8/D1: R95.2, U12.12 (D1); also elsewhere on the board
/RJ45/SchieberegisterInput8/D2: R94.2, U12.13 (D2); also elsewhere on the board
/RJ45/SchieberegisterInput8/D3: R93.2, U12.14 (D3); also elsewhere on the board
/RJ45/SchieberegisterInput8/D4: R92.2, U12.3 (D4); also elsewhere on the board
/RJ45/SchieberegisterInput8/D5: R91.2, U12.4 (D5); also elsewhere on the board
/RJ45/SchieberegisterInput8/D6: R90.2, U12.5 (D6); also elsewhere on the board
/RJ45/SchieberegisterInput8/D7: R89.2, U12.6 (D7); also elsewhere on the board
/RJ45/SchieberegisterInput8/Out: U12.9 (Q7), U13.10 (DS)
/RJ45/SchieberegisterInput9/D0: R104.2, U13.11 (D0); also elsewhere on the board
/RJ45/SchieberegisterInput9/D1: R103.2, U13.12 (D1); also elsewhere on the board
/RJ45/SchieberegisterInput9/D2: R102.2, U13.13 (D2); also elsewhere on the board
/RJ45/SchieberegisterInput9/D3: R101.2, U13.14 (D3); also elsewhere on the board
/RJ45/SchieberegisterInput9/D4: R100.2, U13.3 (D4); also elsewhere on the board
/RJ45/SchieberegisterInput9/D5: R99.2, U13.4 (D5); also elsewhere on the board
/RJ45/SchieberegisterInput9/D6: R98.2, U13.5 (D6); also elsewhere on the board
/RJ45/SchieberegisterInput9/D7: R97.2, U13.6 (D7); also elsewhere on the board
/RJ45/SchieberegisterInput10/D0: R112.2, U14.11 (D0); also elsewhere on the board
/RJ45/SchieberegisterInput10/D1: R111.2, U14.12 (D1); also elsewhere on the board
/RJ45/SchieberegisterInput10/D2: R110.2, U14.13 (D2); also elsewhere on the board
/RJ45/SchieberegisterInput10/D3: R109.2, U14.14 (D3); also elsewhere on the board
/RJ45/SchieberegisterInput10/D4: R108.2, U14.3 (D4); also elsewhere on the board
/RJ45/SchieberegisterInput10/D5: R107.2, U14.4 (D5); also elsewhere on the board
/RJ45/SchieberegisterInput10/D6: R106.2, U14.5 (D6); also elsewhere on the board
/RJ45/SchieberegisterInput10/D7: R105.2, U14.6 (D7); also elsewhere on the board
/RJ45/SchieberegisterInput10/In: U13.9 (Q7), U14.10 (DS)
/RJ45/SchieberegisterInput10/Out: U14.9 (Q7), U15.10 (DS)
/RJ45/SchieberegisterInput11/D0: R120.2, U15.11 (D0); also elsewhere on the board
/RJ45/SchieberegisterInput11/D1: R119.2, U15.12 (D1); also elsewhere on the board
/RJ45/SchieberegisterInput11/D2: R118.2, U15.13 (D2); also elsewhere on the board
/RJ45/SchieberegisterInput11/D3: R117.2, U15.14 (D3); also elsewhere on the board
/RJ45/SchieberegisterInput11/D4: R116.2, U15.3 (D4); also elsewhere on the board
/RJ45/SchieberegisterInput11/D5: R115.2, U15.4 (D5); also elsewhere on the board
/RJ45/SchieberegisterInput11/D6: R114.2, U15.5 (D6); also elsewhere on the board
/RJ45/SchieberegisterInput11/D7: R113.2, U15.6 (D7); also elsewhere on the board
/RJ45/SchieberegisterInput/Out: U5.10 (DS); also elsewhere on the board
Data_Clk: U5.2 (CP), U6.2 (CP), U7.2 (CP), U8.2 (CP), U9.2 (CP), U10.2 (CP), U11.2 (CP), U12.2 (CP), U13.2 (CP), U14.2 (CP), U15.2 (CP); also elsewhere on the board
Data_Latch: U5.1 (~PL), U6.1 (~PL), U7.1 (~PL), U8.1 (~PL), U9.1 (~PL), U10.1 (~PL), U11.1 (~PL), U12.1 (~PL), U13.1 (~PL), U14.1 (~PL), U15.1 (~PL); also elsewhere on the board
Data_Output: U15.9 (Q7); also elsewhere on the board
GND: C13.2, C22.2, C31.2, C40.2, C49.2, C58.2, C67.2, C76.2, C85.2, C94.2, C103.2, R122.2, R123.2, R124.2, R125.2, R126.2, R127.2, R128.2, R129.2, R130.2, R131.2, R132.2, U5.8 (GND), U6.8 (GND), U7.8 (GND), U8.8 (GND), U9.8 (GND), U10.8 (GND), U11.8 (GND), U12.8 (GND), U13.8 (GND), U14.8 (GND), U15.8 (GND); also elsewhere on the board
unnamed: R123.1, U5.15 (~CE)
unnamed: R122.1, U6.15 (~CE)
unnamed: R124.1, U7.15 (~CE)
unnamed: R125.1, U8.15 (~CE)
unnamed: R126.1, U9.15 (~CE)
unnamed: R127.1, U10.15 (~CE)
unnamed: R128.1, U11.15 (~CE)
unnamed: R129.1, U12.15 (~CE)
unnamed: R130.1, U13.15 (~CE)
unnamed: R131.1, U14.15 (~CE)
unnamed: R132.1, U15.15 (~CE)

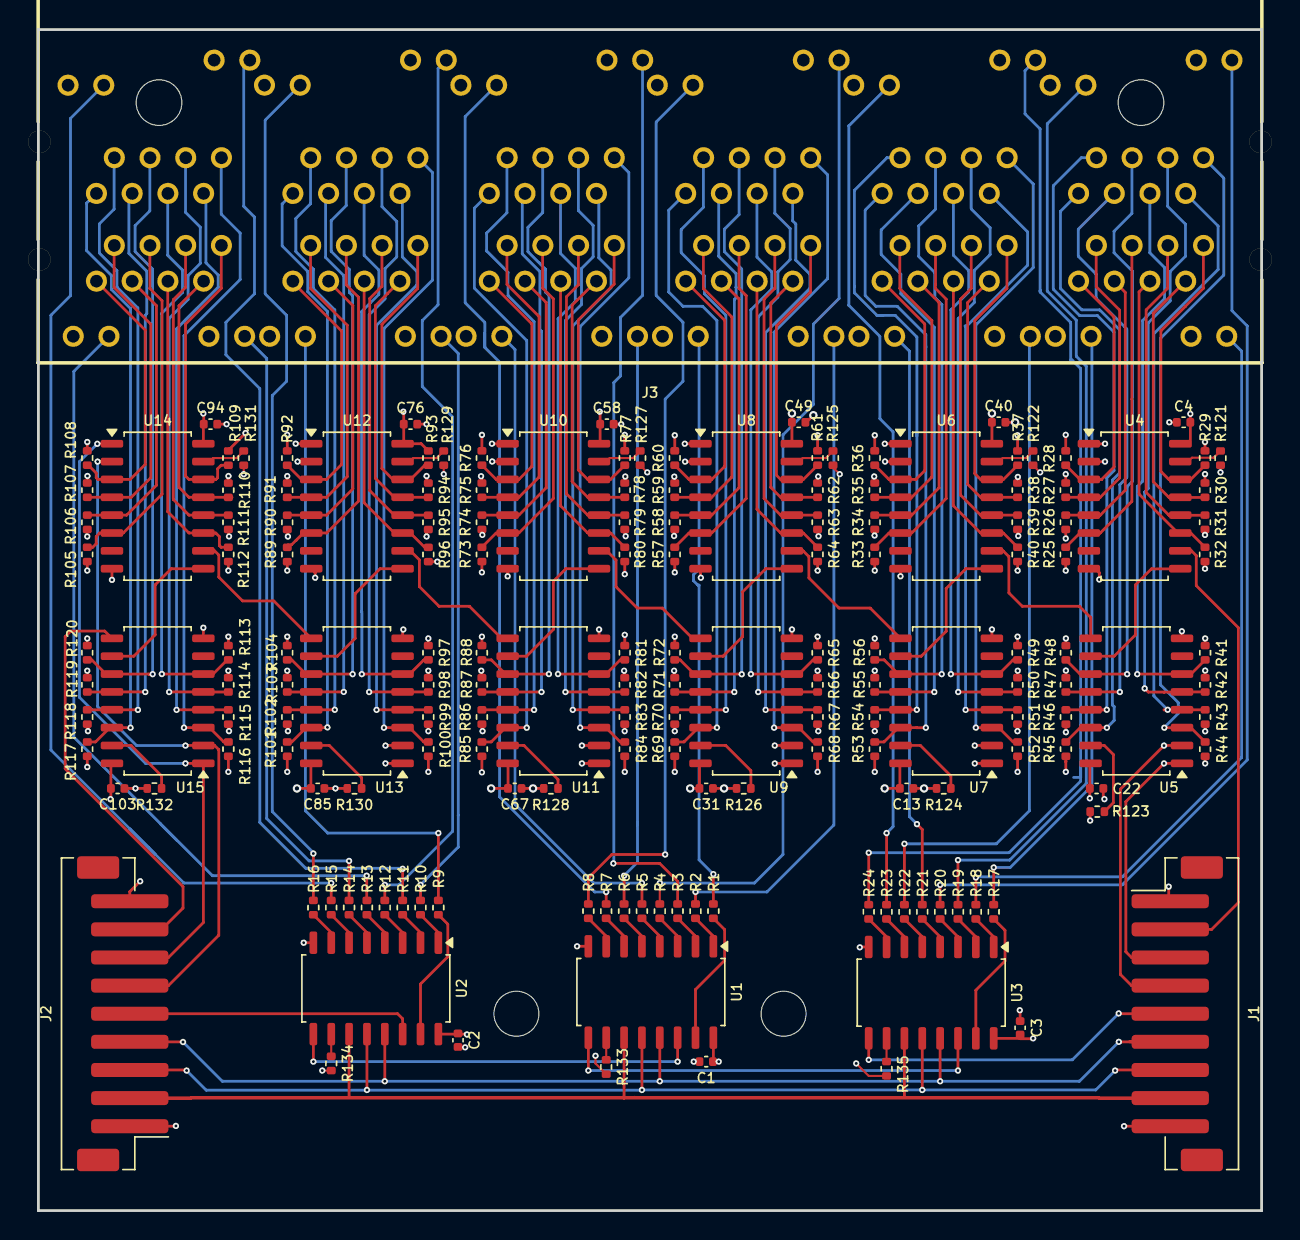
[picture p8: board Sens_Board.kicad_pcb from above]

Board: 4 copper layers, 87.0 x 84.0 mm, 170 parts (0 on the bottom side), 183 nets.

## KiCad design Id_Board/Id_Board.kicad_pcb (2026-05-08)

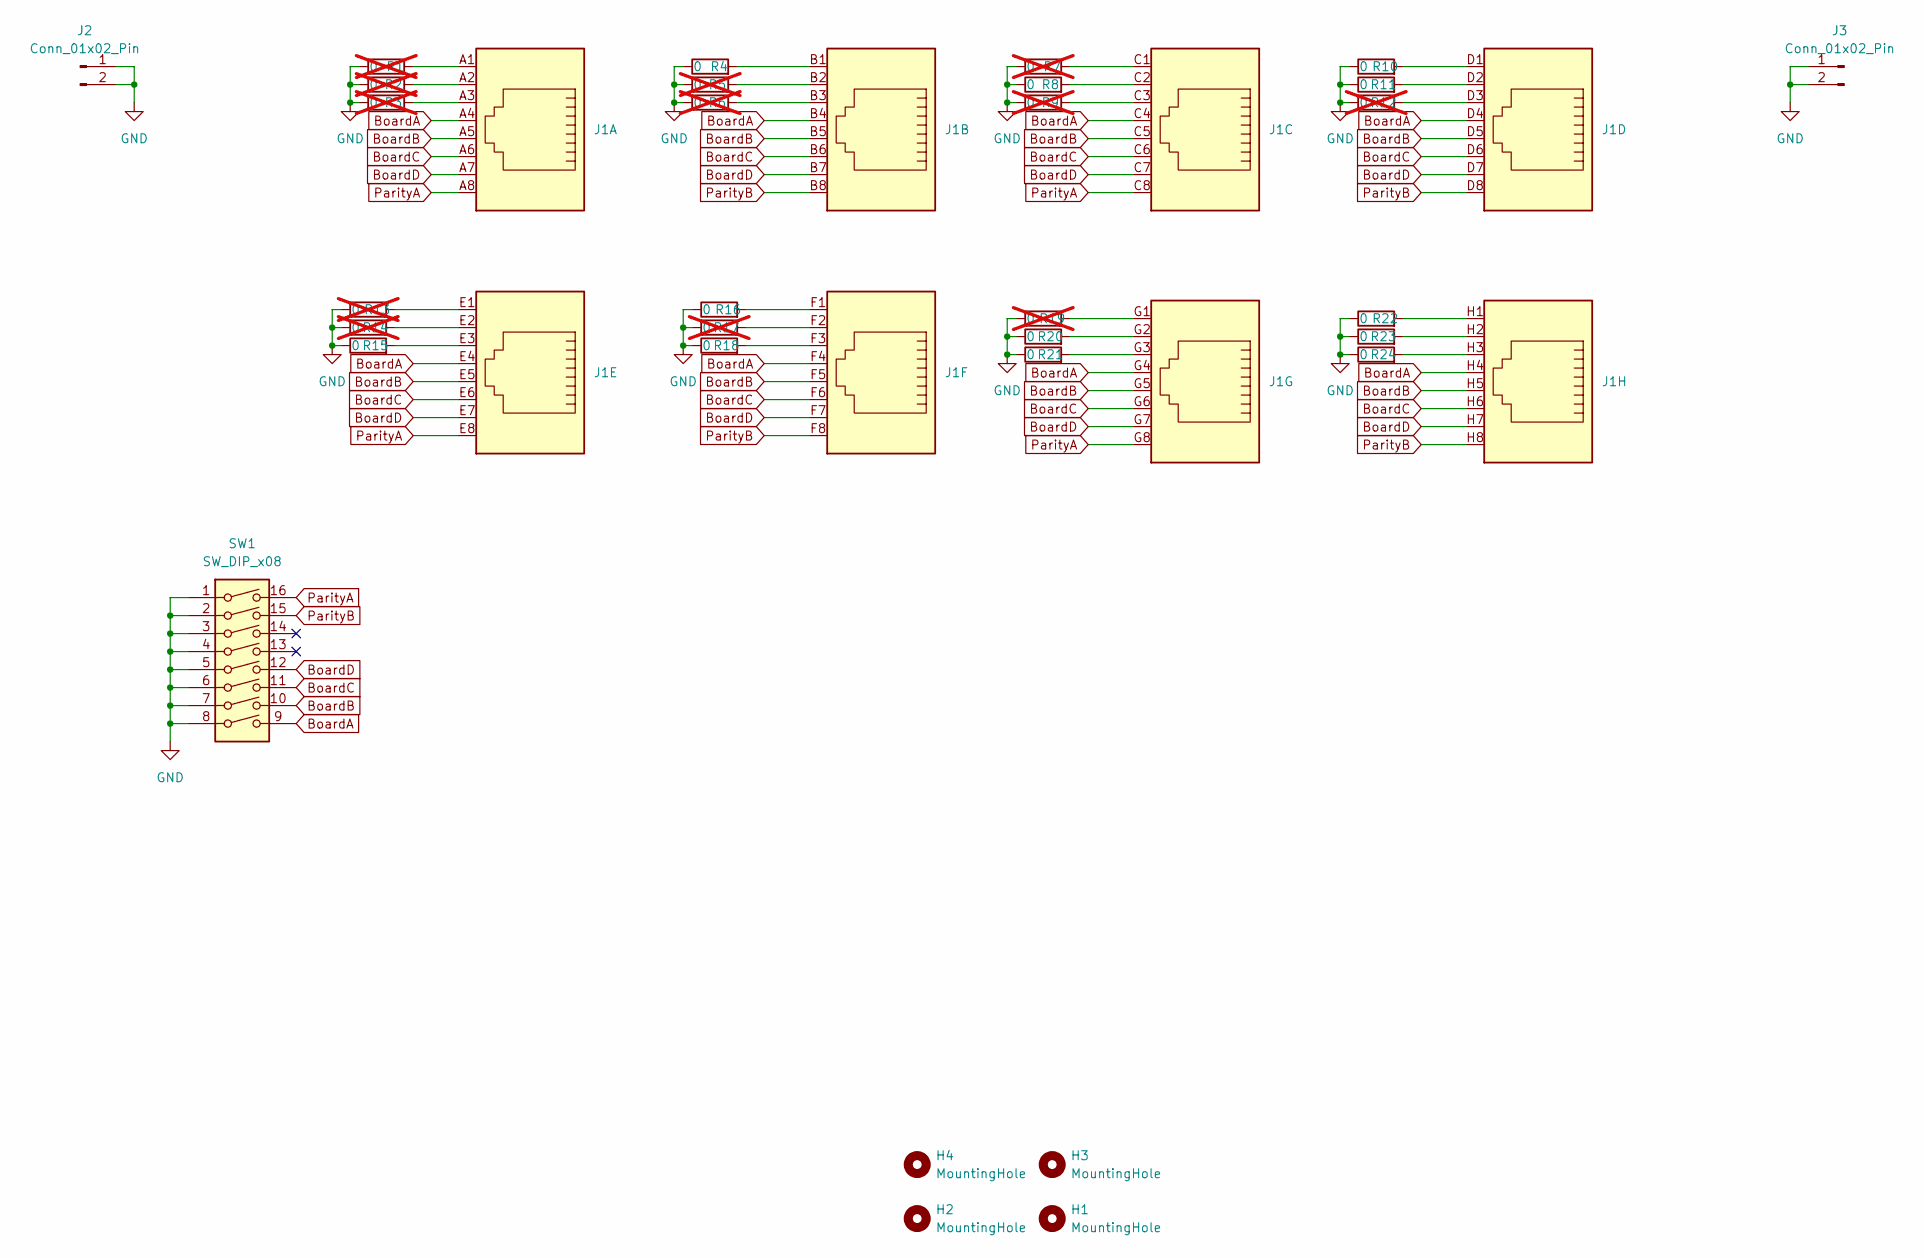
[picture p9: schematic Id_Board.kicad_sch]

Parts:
H1, H2, H3, H4: MountingHole; MountingHole_3.2mm_M3
J1: RJ45-TH_HC-WK88-H13-1X8-55QS_1
J2, J3: Conn_01x02_Pin; JST_PH_B2B-PH-SM4-TB_1x02-1MP_P2.00mm_Vertical
R1, R2, R3, R5, R6, R7, R9, R12, R13, R14, R17, R19: 0; R_0603_1608Metric; not fitted
R4, R8, R10, R11, R15, R16, R18, R20, R21, R22, R23, R24: 0; R_0603_1608Metric
SW1: SW_DIP_x08; SW-SMD_16P-L20.3-W6.0-P2.54-LS9.3-BL

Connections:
BoardA: J1.A4, J1.B4, J1.C4, J1.D4, J1.E4, J1.F4, J1.G4, J1.H4, SW1.9
BoardB: J1.A5, J1.B5, J1.C5, J1.D5, J1.E5, J1.F5, J1.G5, J1.H5, SW1.10
BoardC: J1.A6, J1.B6, J1.C6, J1.D6, J1.E6, J1.F6, J1.G6, J1.H6, SW1.11
BoardD: J1.A7, J1.B7, J1.C7, J1.D7, J1.E7, J1.F7, J1.G7, J1.H7, SW1.12
GND: J2.1, J2.2, J3.1, J3.2, R1.1, R2.1, R3.1, R4.1, R5.1, R6.1, R7.1, R8.1, R9.1, R10.1, R11.1, R12.1, R13.1, R14.1, R15.1, R16.1, R17.1, R18.1, R19.1, R20.1, R21.1, R22.1, R23.1, R24.1, SW1.1, SW1.2, SW1.3, SW1.4, SW1.5, SW1.6, SW1.7, SW1.8
unnamed: J1.A1, R1.2
unnamed: J1.A2, R2.2
unnamed: J1.A3, R3.2
unnamed: J1.B1, R4.2
unnamed: J1.B2, R5.2
unnamed: J1.B3, R6.2
unnamed: J1.C1, R7.2
unnamed: J1.C2, R8.2
unnamed: J1.C3, R9.2
unnamed: J1.D1, R10.2
unnamed: J1.D2, R11.2
unnamed: J1.D3, R12.2
unnamed: J1.E1, R13.2
unnamed: J1.E2, R14.2
unnamed: J1.E3, R15.2
unnamed: J1.F1, R16.2
unnamed: J1.F2, R17.2
unnamed: J1.F3, R18.2
unnamed: J1.G1, R19.2
unnamed: J1.G2, R20.2
unnamed: J1.G3, R21.2
unnamed: J1.H1, R22.2
unnamed: J1.H2, R23.2
unnamed: J1.H3, R24.2
ParityA: J1.A8, J1.C8, J1.E8, J1.G8, SW1.16
ParityB: J1.B8, J1.D8, J1.F8, J1.H8, SW1.15

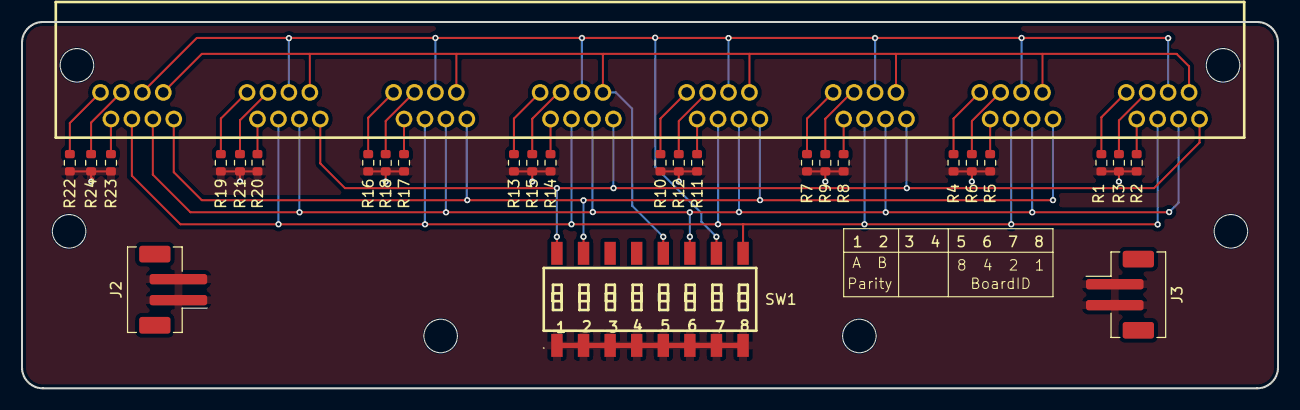
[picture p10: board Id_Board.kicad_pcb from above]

Board: 2 copper layers, 120.0 x 35.0 mm, 32 parts (0 on the bottom side), 31 nets.

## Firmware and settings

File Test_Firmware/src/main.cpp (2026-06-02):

#include <Arduino.h>

static const int PIN_LED_CLK    = 14;
static const int PIN_LED_LATCH  = 13;
static const int PIN_LED_OE     = 10;  // active low
static const int PIN_LED_DOUT   = 15;
static const int PIN_DATA_CLK   = 18;
static const int PIN_DATA_LATCH = 17;
static const int PIN_DATA_DIN   = 16;

static const int NUM_PORTS = 48;

static const int NUM_PORTS_PER_BANK = 12;
static const int NUM_LEDS = NUM_PORTS * 2;
static const size_t NUM_LED_BYTES = (NUM_LEDS + 7) / 8;

uint8_t ledData[NUM_LED_BYTES] = {0};
uint8_t portData[NUM_PORTS] = {0};



static const uint8_t ledIdxMapping[] = {
  // Y,  G
     1,  0,     // Port 0
     3,  2,
     5,  4,
     7,  6,
     9,  8, 
    11, 15,     // Port 5 (green swapped with yellow of port 7)
    13, 12,
    10, 14,     // Port 7 (yellow swapped with green of port 5)
    17, 16,
    19, 23,     // Port 9 (green swapped with yellow of port 11)
    21, 20,
    18, 22,     // Port 11 (yellow swapped with green of port 9)
};


void updateLeds() {
    for (int i = 0; i < NUM_LED_BYTES; i++) {
        shiftOut(PIN_LED_DOUT, PIN_LED_CLK, MSBFIRST, ledData[i]);
    }
    digitalWrite(PIN_LED_LATCH, LOW);
    digitalWrite(PIN_LED_LATCH, HIGH);
}

// led: 0 = yellow, 1 = green
void setLed(int port, int led, bool state) {
    int ledIdx = port * 2 + led;
    int portBankOffset = (ledIdx / 2 / NUM_PORTS_PER_BANK) * NUM_PORTS_PER_BANK * 2;
    int mappedIdx = ledIdxMapping[ledIdx % (NUM_PORTS_PER_BANK*2)] + portBankOffset;

    if (state) {
        ledData[mappedIdx / 8] |= 1 << (mappedIdx % 8);
    }
    else {
        ledData[mappedIdx / 8] &= ~(1 << (mappedIdx % 8));
    }
}


void setup() {
    pinMode(PIN_LED_CLK, OUTPUT);
    pinMode(PIN_LED_LATCH, OUTPUT);
    digitalWrite(PIN_LED_OE, HIGH);
    pinMode(PIN_LED_OE, OUTPUT);
    pinMode(PIN_LED_DOUT, OUTPUT);
    pinMode(PIN_DATA_CLK, OUTPUT);
    digitalWrite(PIN_DATA_CLK, HIGH);
    pinMode(PIN_DATA_LATCH, OUTPUT);

    analogWrite(PIN_LED_OE, 127);

    Serial.begin(115200);

    for (int i = 0; i < NUM_LEDS; i++) {
        memset(ledData, 0, sizeof(ledData));
        setLed(i/2, i%2, 1);
        updateLeds();
        delay(25);
    }
    memset(ledData, 0, sizeof(ledData));
    updateLeds();
}


uint32_t ledIdx = 0;

void loop() {
    ledIdx++;
    if (ledIdx >= NUM_LEDS) {
        ledIdx = 0;
    }
    
    memset(ledData, 0, sizeof(ledData));
    updateLeds();

    digitalWrite(PIN_DATA_LATCH, LOW);
    digitalWrite(PIN_DATA_LATCH, HIGH);
    for (int i = 0; i < NUM_PORTS; i++) {
        // portData[i] = shiftIn(PIN_DATA_DIN, PIN_DATA_CLK, MSBFIRST);
        // Serial.print(portData[i], 2);
        // Serial.print(" ");

        portData[i] = 0;
        for (int bit = 0; bit < 8; bit++) {
            portData[i] |= digitalRead(PIN_DATA_DIN) << bit;
            digitalWrite(PIN_DATA_CLK, LOW);
            digitalWrite(PIN_DATA_CLK, HIGH);
        }

        if (portData[i] != 0xFF) {
            setLed(NUM_PORTS - i - 1, 0, (ledIdx % 2));
            setLed(NUM_PORTS - i - 1, 1, !(ledIdx % 2));
            updateLeds();
        }

        char buf[64];
        int len = snprintf(buf, sizeof(buf), "%02X ", portData[i]);
        Serial.write(buf, len);
    }
    Serial.println();


    delay(100);
}

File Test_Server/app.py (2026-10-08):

import random
import re
import sqlite3
import threading
import time
from dataclasses import asdict, dataclass

import serial
from flask import Flask, jsonify, render_template, request
from flask_socketio import SocketIO

from board import EXPECTED_IDS, NUM_PORTS, OPEN_ID
from gamemodes import BUILTIN_MODES
from leaderboard import LeaderboardStore, NewLeaderboardEntry, default_database_path
from race import Phase, RaceStateMachine

MAX_SAFE_INTEGER = 2**53 - 1


def decode_serial_frame(line: bytes) -> tuple[int, ...]:
    tokens = line.decode("ascii").split()
    if len(tokens) != NUM_PORTS or any(
        re.fullmatch(r"[0-9A-Fa-f]{1,2}", token) is None for token in tokens
    ):
        raise ValueError("expected 48 hexadecimal byte identities")
    return tuple(int(token, 16) for token in reversed(tokens))


def safe_integer(value, minimum=0):
    return type(value) is int and minimum <= value <= MAX_SAFE_INTEGER


@dataclass
class BrowseToken:
    request_id: int
    origin: object
    boundary: int | None
    opening: bool = False


class UnavailableLeaderboardStore:
    def selected_slot(self):
        raise OSError("Leaderboard store is unavailable")

    def set_selected_slot(self, leaderboard_slot):
        raise OSError("Leaderboard store is unavailable")

    def insert_entries(self, entries):
        raise OSError("Leaderboard store is unavailable")

    def snapshot_boundary(self, mode_id, leaderboard_slot=1):
        raise OSError("Leaderboard store is unavailable")

    def page_entries(
        self, mode_id, boundary, offset, limit=50, leaderboard_slot=1, race_id=None
    ):
        raise OSError("Leaderboard store is unavailable")


class GameRuntime:
    def __init__(self, socketio, race, store, logger):
        self.socketio = socketio
        self.race = race
        self.store = store
        self.logger = logger
        self._browsing = {}
        self._browse_lock = threading.Lock()
        self._publication_lock = threading.RLock()
        self.serial_threads = None
        self.stop_serial = False
        self._serial_lock = threading.Lock()

    def observe_board(self, player_number, values):
        self.apply(self.race.observe_board, player_number, values)

    def apply(self, operation, *args):
        with self._publication_lock:
            change = operation(*args)
            self._publish_change(change)
        self._after_change(change)
        return change

    def handle_change(self, change):
        with self._publication_lock:
            self._publish_change(change)
        self._after_change(change)

    def select_leaderboard_slot(self, leaderboard_slot):
        with self._publication_lock:
            error = None
            accepted = False
            if type(leaderboard_slot) is not int or not 1 <= leaderboard_slot <= 9:
                error = "Leaderboard slot must be an integer between 1 and 9"
            elif self.race.snapshot()["phase"] != Phase.READY:
                error = "Leaderboard slot selection is only available when ready"
            else:
                try:
                    self.store.set_selected_slot(leaderboard_slot)
                except (sqlite3.Error, OSError, ValueError):
                    self.logger.exception("Could not save selected leaderboard slot")
                    error = "Leaderboard slot could not be saved"
                else:
                    change = self.race.select_leaderboard_slot(leaderboard_slot)
                    self._publish_change(change)
                    accepted = change.action == "leaderboard_slot_selected"
            return {
                "accepted": accepted,
                "leaderboard_slot": self.race.snapshot()["leaderboard_slot"],
                "error": error,
            }

    def _publish_change(self, change):
        if change.diagnostic:
            self.logger.error("Mode evaluation failed: %s", change.diagnostic)
        if change.changed:
            self.emit_state()

    def _after_change(self, change):
        if change.action == "leaderboard":
            self._persist(change.origin, change.submissions)

    def _persist(self, origin, submissions):
        persistence_error = None
        try:
            self.store.insert_entries(
                [
                    NewLeaderboardEntry(
                        race_id=item.race_id,
                        mode_id=item.mode_id,
                        player_number=item.player_number,
                        name=item.name,
                        duration_ms=item.duration_ms,
                        leaderboard_slot=item.leaderboard_slot,
                    )
                    for item in submissions
                ]
            )
        except (sqlite3.Error, OSError, ValueError):
            self.logger.exception("Could not save leaderboard scores")
            persistence_error = "Scores could not be saved"
        self.apply(self.race.set_persistence, origin, persistence_error)

    def emit_state(self, to=None):
        snapshot = self.race.snapshot()
        self.socketio.emit("game_state", snapshot, to=to)
        for number, player in snapshot["players"].items():
            presentation = player["presentation"]
            if presentation is not None:
                self.socketio.emit(
                    "table_update",
                    {
                        "switch_id": int(number),
                        "revision": snapshot["revision"],
                        "states": [
                            {"correct": 2, "wrong": 1}.get(port["feedback"], 0)
                            for port in presentation["ports"]
                        ],
                    },
                    to=to,
                )
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

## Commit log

2026-04-29 add Boards
    [DipSwitch.kicad_sch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]
2026-04-30 finished IdBoard
    [DipSwitch.kicad_sch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]
2026-04-30 Senssoard Firsat LAyout start
    [OutputShift.kicad_sch, RJ45.kicad_sch, SchieberegisterInput.kicad_sch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]
2026-05-01 set Komponents SensorBoard
    [RJ45.kicad_sch, SchieberegisterInput.kicad_sch, Sens_Board.kicad_pcb]
2026-05-05 finish SensBoard
    [RJ45.kicad_sch, SchieberegisterInput.kicad_sch, Sens_Board.kicad_pcb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]
2026-05-05 add pull UP/DOWN
    [OutputShift.kicad_sch, SchieberegisterInput.kicad_sch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]
2026-05-05 fixes and optmierung
    [RJ45.kicad_sch, SchieberegisterInput.kicad_sch, Sens_Board.kicad_pcb]
2026-05-05 Production File generate
    [Id_Board-CuBottom.gbr, Id_Board-CuTop.gbr, Id_Board-EdgeCuts.gbr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]
2026-05-05 prettify silkscreen
    [Id_Board.kicad_pcb, Sens_Board.kicad_pcb]
2026-05-08 update production files
    [Id_Board-CuBottom.gbr, Id_Board-CuTop.gbr, Id_Board-EdgeCuts.gbr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]
2026-05-08 add production files ID board
    [Id_Board-CuBottom.gbr, Id_Board-CuTop.gbr, Id_Board-EdgeCuts.gbr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]
2026-05-08 add .csv
    [BOM-Id_Board.csv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]
2026-05-08 add production files Sens
    [BOM-Sens_Board.csv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]
2026-05-08 update Cnumbers
    [BOM-Sens_Board.csv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]
2026-05-08 update JST Economic
    [BOM-Sens_Board.csv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]
2026-05-28 add Mechanic Files
    [AbstandhalterSwitchPCB.stl, BlendePatchpannel1.stl, BlendePatchpannel2.stl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]
2026-06-08 chore(ui): vendor socket.io client
2026-06-28 Add ability to verify
    Also add:
    - Remove Right and Left Player icon, players are 1 and 2
    - Add V and S keys for toggling verify and restarting the serial threads
    - Rename Paused to Stopped
    This intentionally leaves the topic of miliseconds open
2026-08-28 feat(server): add post-race name flow
2026-08-28 fix(server): keep kiosk available without database
    [app.py]
2026-08-29 fix(ui): submit both names on enter
    [race.py]
2026-10-08 feat: add persistent leaderboard slots
2026-10-08 fix(ui): keep switch boards in flexible grid row
